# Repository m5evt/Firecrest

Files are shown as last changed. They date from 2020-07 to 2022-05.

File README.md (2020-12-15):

# Firecrest
This project is a dual band band HF CW transceiver design with a focus on portable operating. The design is realised across 3 stacked PCBs and the receiver is very similar to the N7VE/Norcal NC2030 and the transmitter PA is very similar to the KD1JV series of MTR rigs. This is not a kit, I intend to write a set of instruction to allow someone else with the appropriate skills to source their own components and build this radio.

Further information is on the [wiki](https://github.com/m5evt/Firecrest/wiki/).

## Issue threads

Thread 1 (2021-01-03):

Kicad files unproven

m5evt, 2021-01-03:
The hardware schematic and PCB files were imported from Eagle PCB. The gerbers from this (eagle) project have been ordered and the boards have been built. These are here [https://github.com/m5evt/Firecrest/tree/master/hardware/gerbers](url). If someone wants to make a modification to the hardware and create new gerbers, please approach with care.

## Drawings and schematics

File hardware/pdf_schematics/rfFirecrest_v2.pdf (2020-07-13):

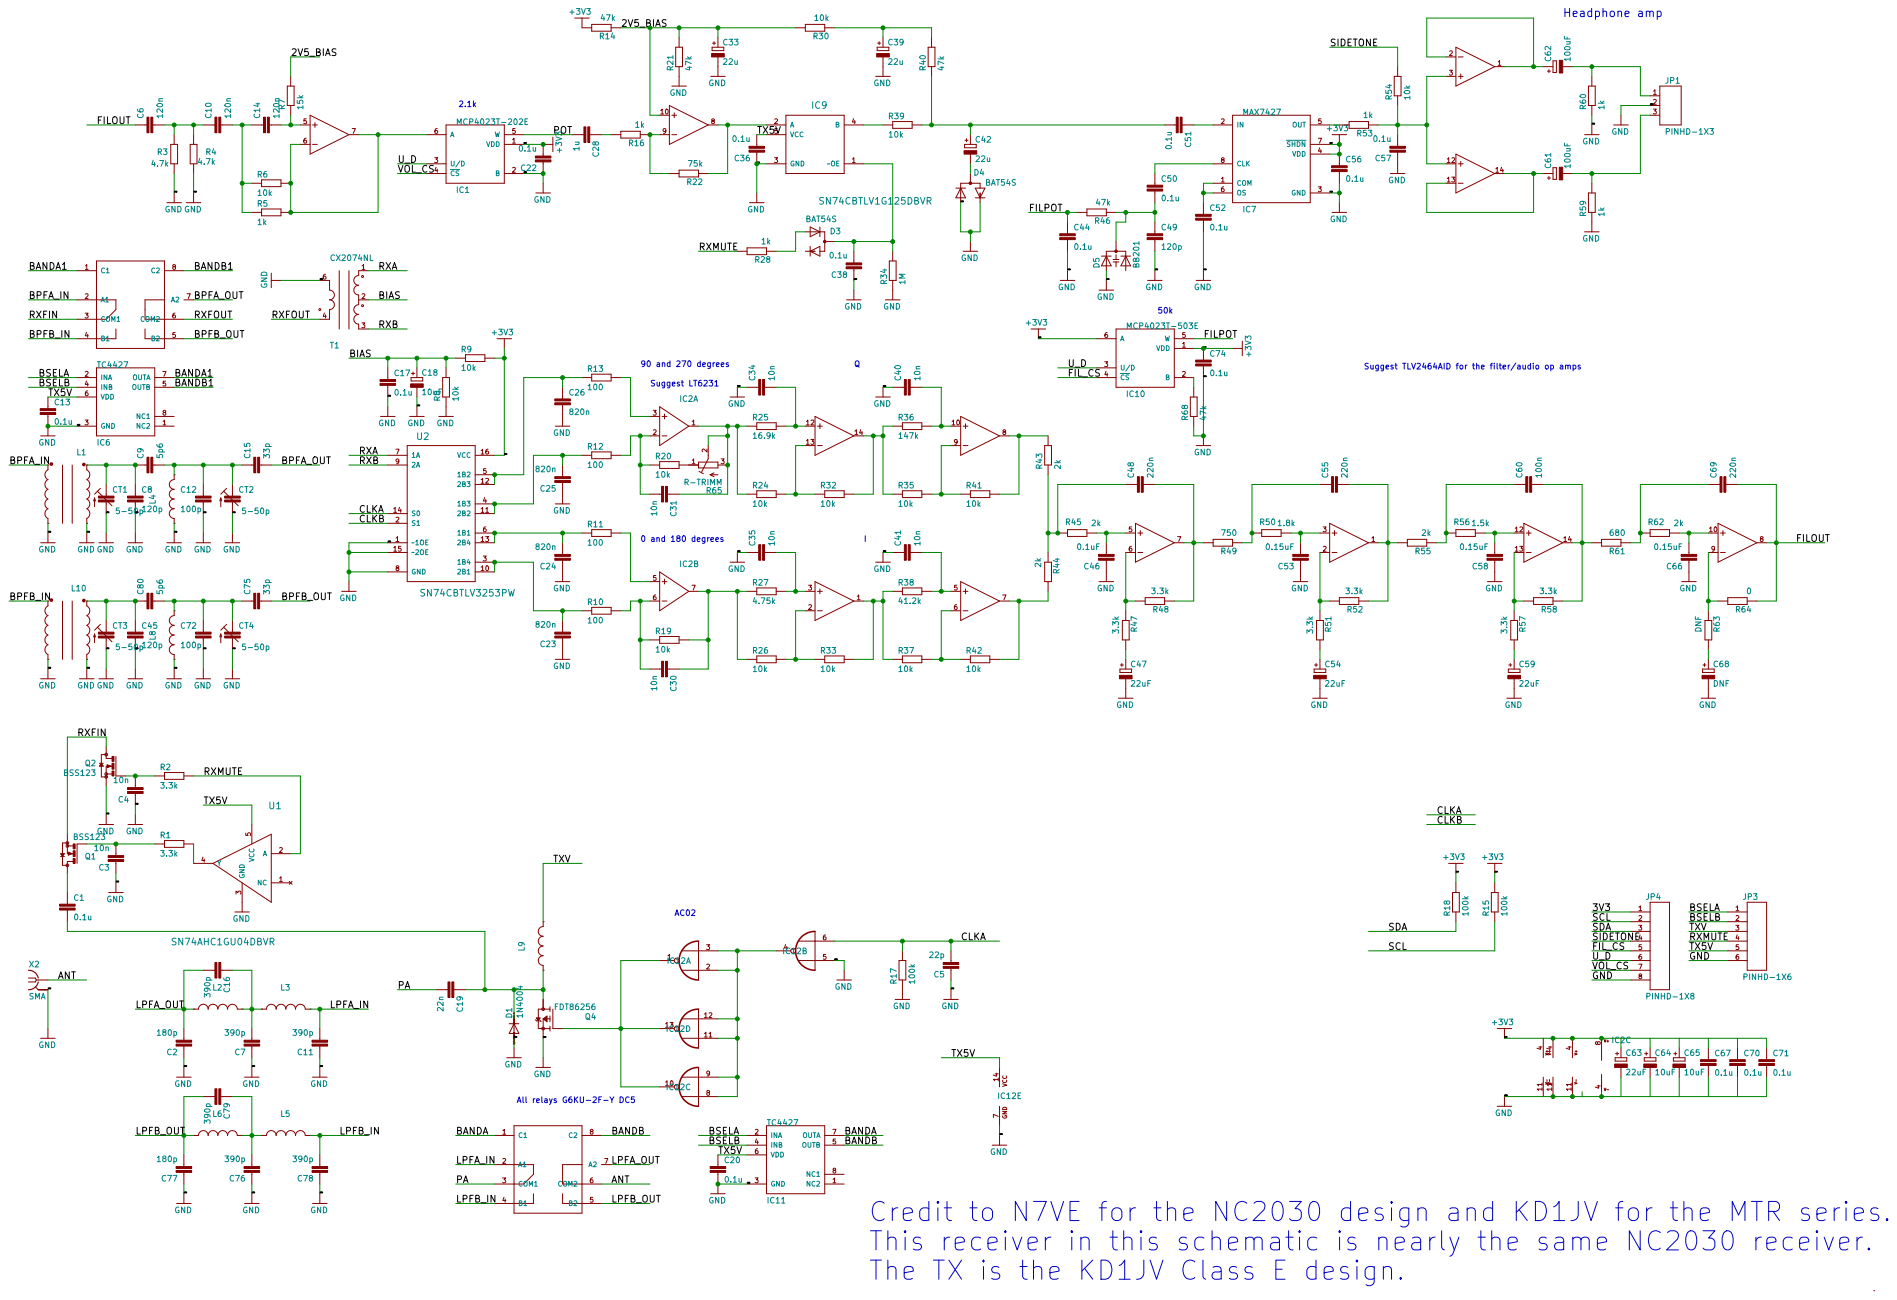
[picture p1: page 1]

Suggest TLV2464AID for the filter/audio op amps

Credit to N7VE for the NC2030 design and KD1JV for the MTR series.
This receiver in this schematic is nearly the same NC2030 receiver.
The TX is the KD1JV Class E design.

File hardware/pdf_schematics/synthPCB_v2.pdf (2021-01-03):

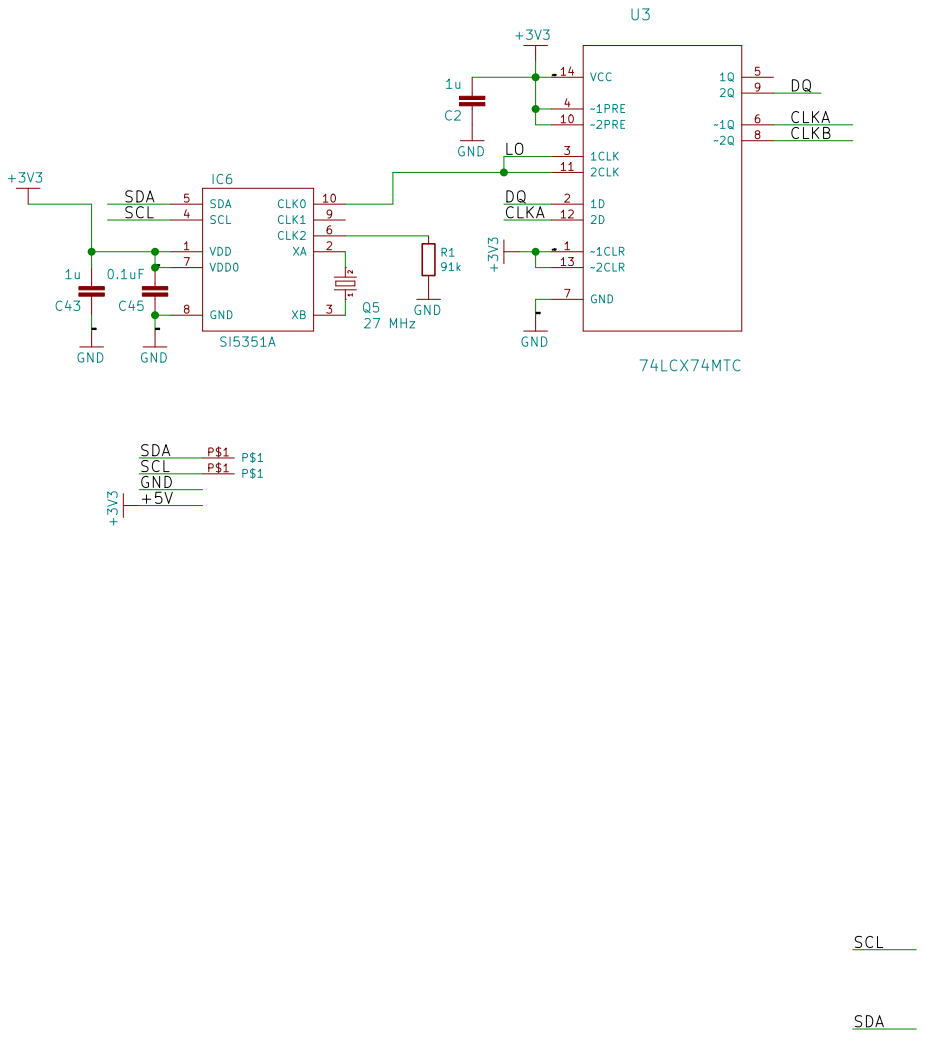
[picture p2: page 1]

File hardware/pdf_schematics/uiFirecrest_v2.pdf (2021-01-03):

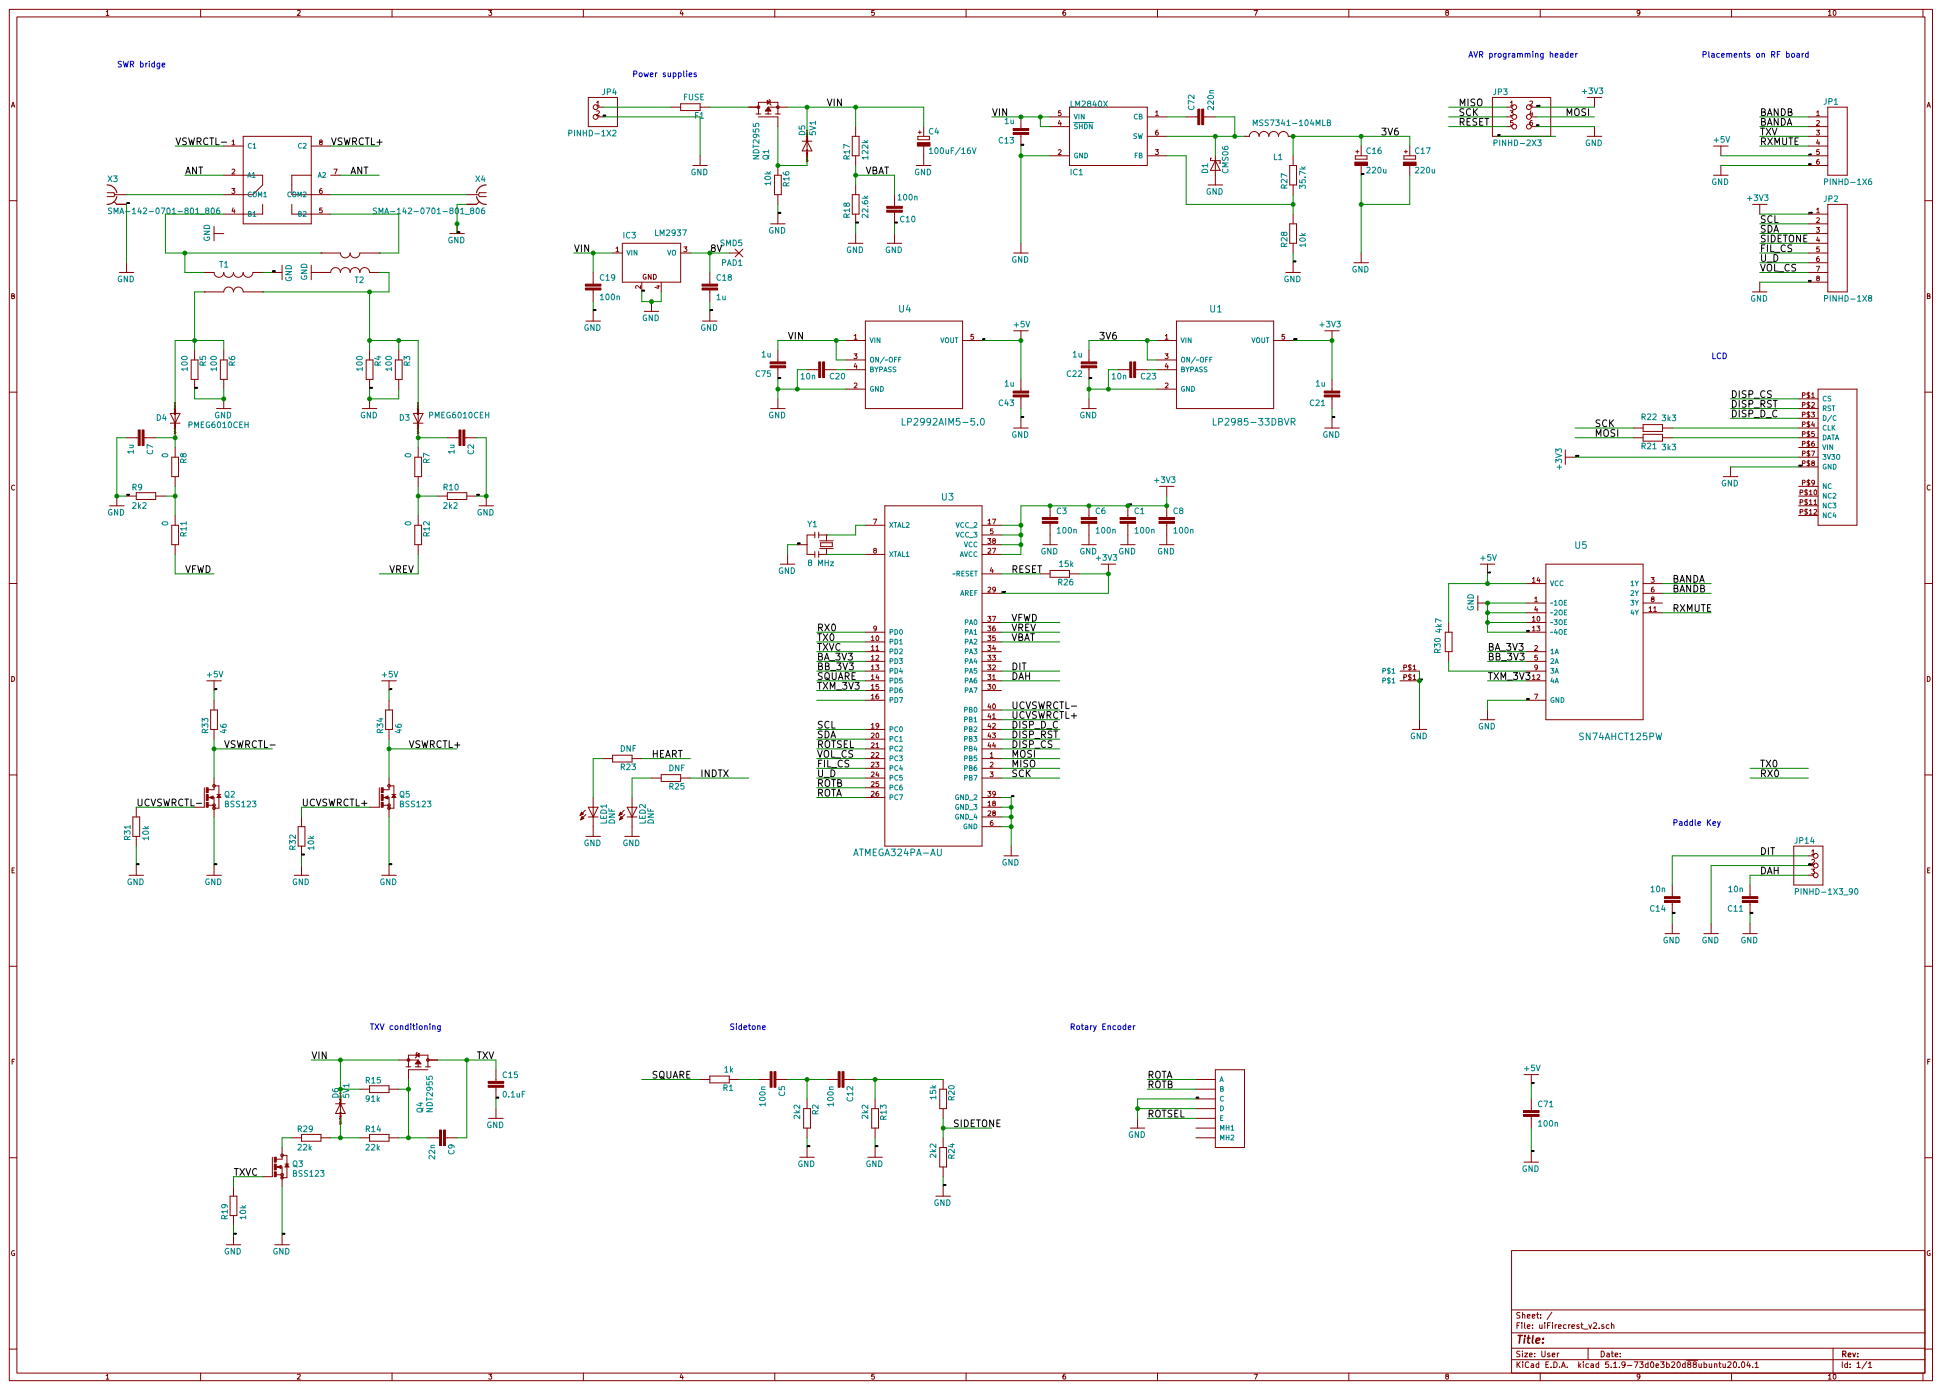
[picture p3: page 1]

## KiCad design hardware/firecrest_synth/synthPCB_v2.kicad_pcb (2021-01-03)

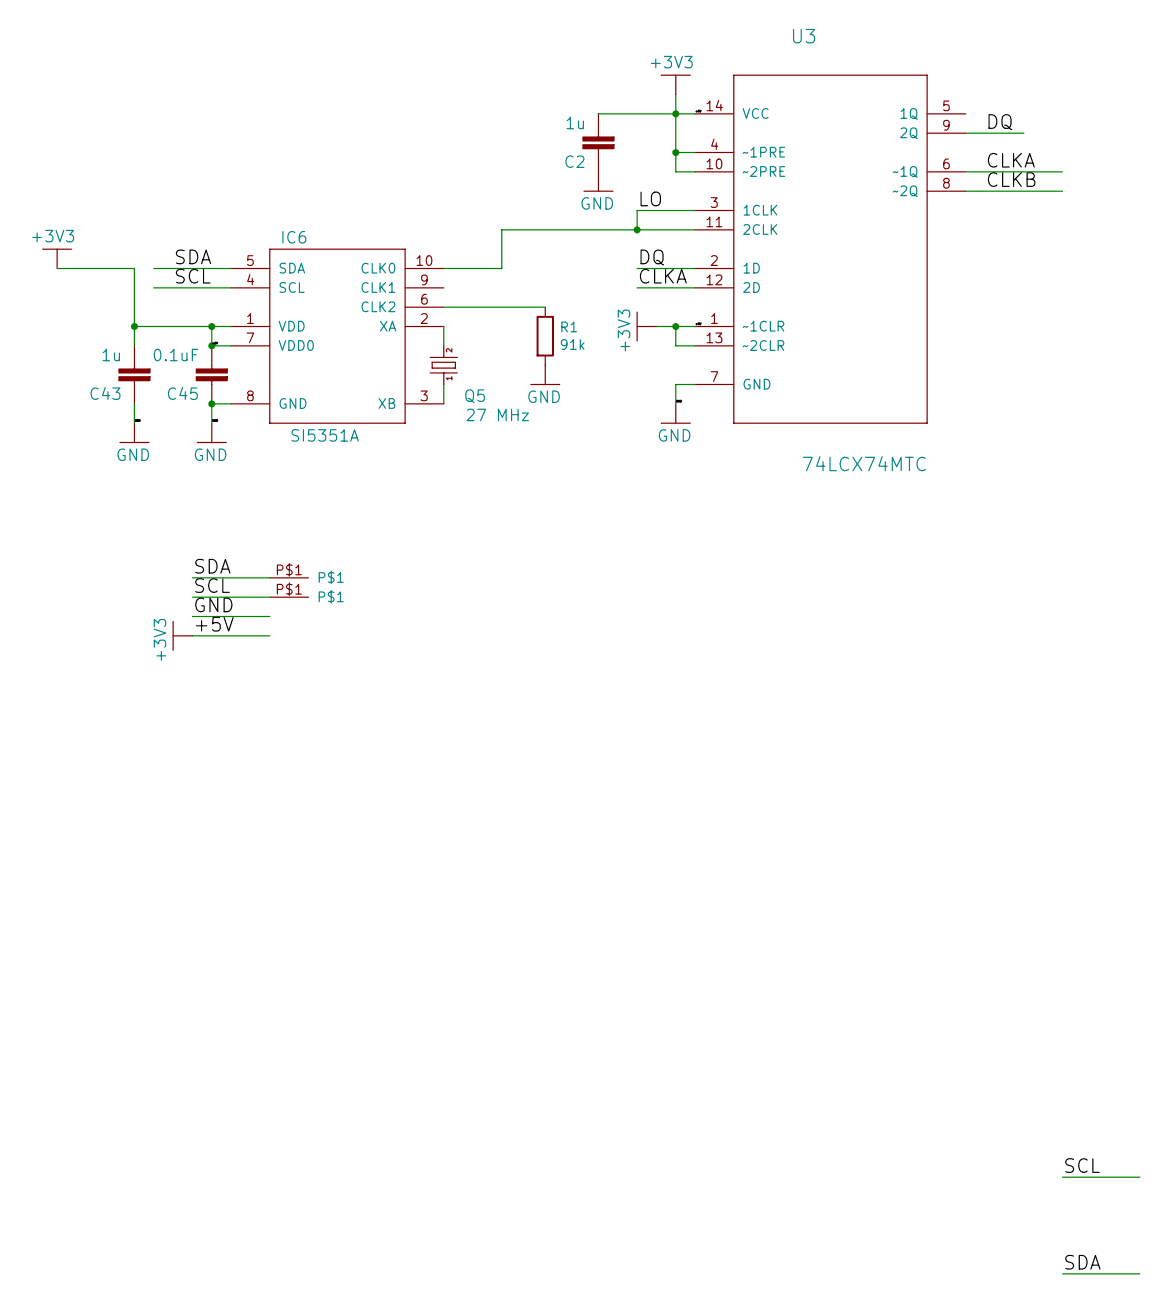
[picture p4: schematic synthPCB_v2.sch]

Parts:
C2, C43: 1u; C0603K
C45: 0.1uF; C0603K
IC6: SI5351A; MSOP10
Q5: 27 MHz; CTS406
R1: 91k; R_0603_1608Metric_Pad0.98x0.95mm_HandSolder
U3: 74LCX74MTC; SOP65P640X120-14N
U$5, U$6: EDGEPAD

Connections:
+5V: C2.2, C43.2, C45.2, IC6.1 (VDD), IC6.7 (VDD0), U3.1 (~~1CLR), U3.4 (~~1PRE), U3.10 (~~2PRE), U3.13 (~~2CLR), U3.14 (VCC)
/CLKA: U3.6 (~~1Q), U3.12 (2D)
/CLKB: U3.8 (~~2Q)
/DQ: U3.2 (1D), U3.9 (2Q)
/LO: IC6.10 (CLK0), U3.3 (1CLK), U3.11 (2CLK)
/SCL: IC6.4 (SCL), U$6.P$1
/SDA: IC6.5 (SDA), U$5.P$1
GND: C2.1, C43.1, C45.1, IC6.8 (GND), R1.2, U3.7 (GND)
unnamed: IC6.2 (XA), Q5.3 (2)
unnamed: IC6.3 (XB), Q5.1
unnamed: IC6.6 (CLK2), R1.1

Board: 2 copper layers, 13 parts (0 on the bottom side), 10 nets.

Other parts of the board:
@HOLE0, @HOLE1, @HOLE2, @HOLE3: (no value)

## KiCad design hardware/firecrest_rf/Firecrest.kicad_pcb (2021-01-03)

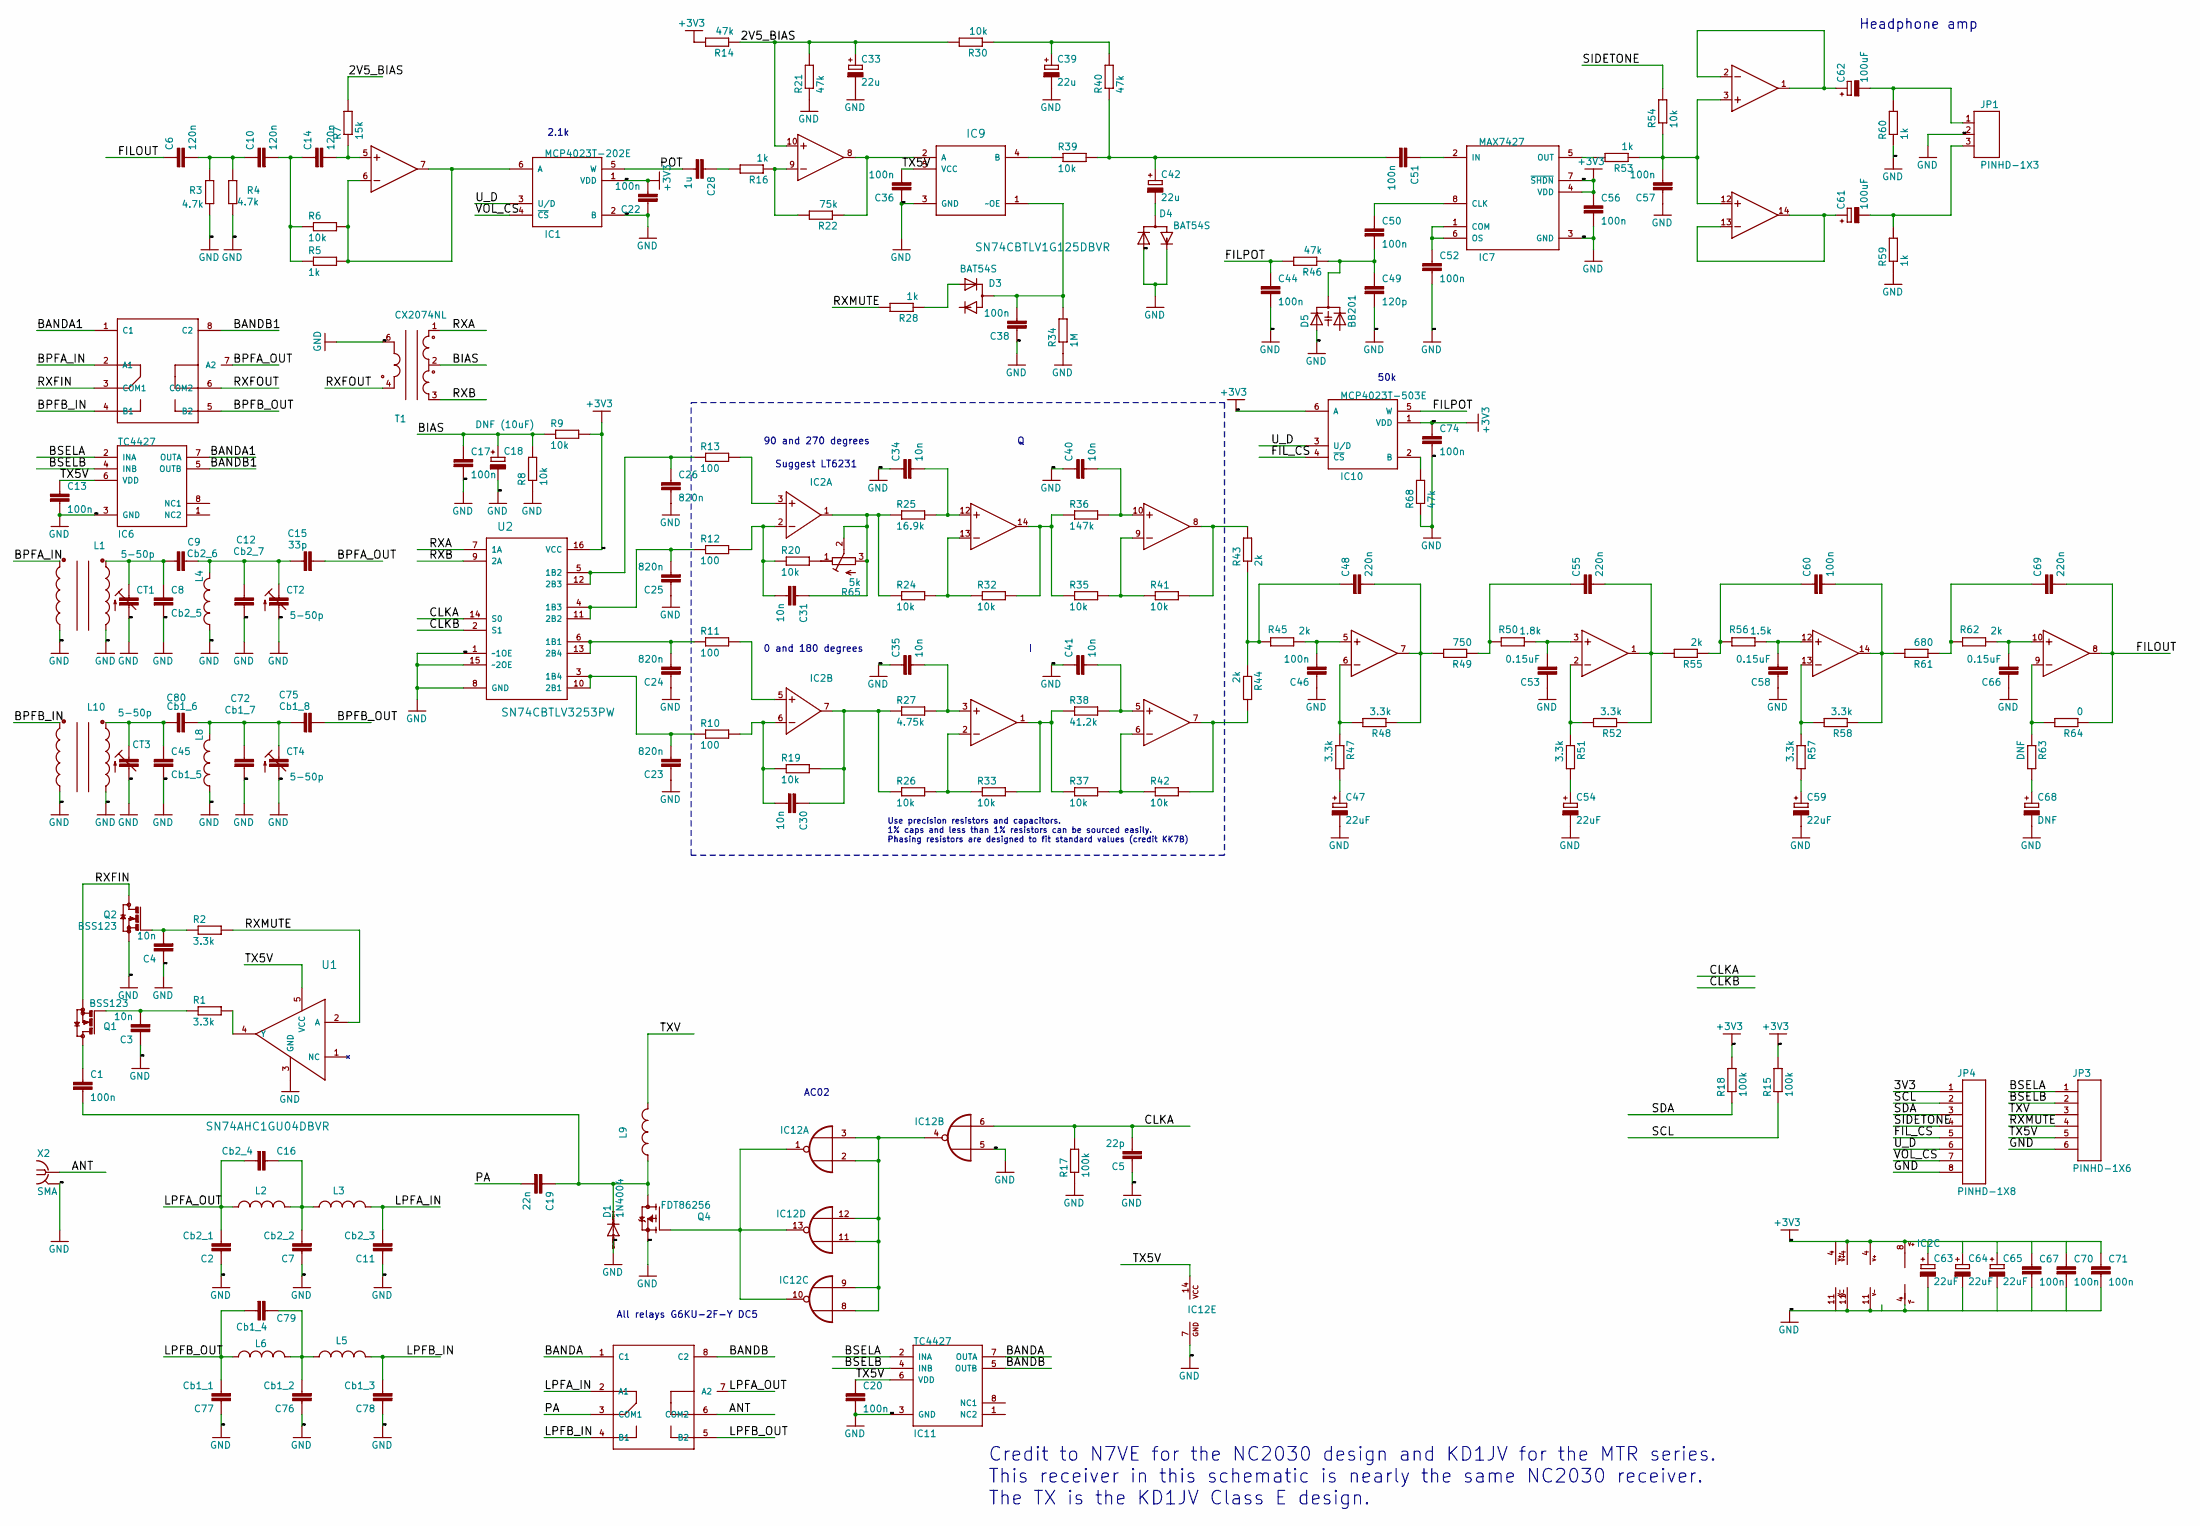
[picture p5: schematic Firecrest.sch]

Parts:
C1: 100n; C0805K
C2: Cb2_1; C0805K
C3, C4, C30, C31, C34, C35, C40, C41: 10n; C0603K
C5: 22p; C0603K
C6, C10, C14: 120n; C0603K
C7: Cb2_2; C0805K
C8: Cb2_5; C0603K
C9: Cb2_6; C0603K
C11: Cb2_3; C0805K
C12: Cb2_7; C0603K
C13, C17, C20, C22, C36, C38, C44, C46, C50, C51, C52, C56, C57, C60, C67, C70, C71, C74: 100n; C0603K
C15: 33p; C0603K
C16: Cb2_4; C0805K
C18: DNF (10uF); SMC_B
C19: 22n; C0805K
C23, C24, C25, C26: 820n; C0603K
C28: 1u; C0603K
C33, C39, C42: 22u; SMC_B
C45: Cb1_5; C0603K
C47, C54, C59, C63, C64, C65: 22uF; SMC_B
C48, C55, C69: 220n; C0603K
C49: 120p; C0603K
C53, C58, C66: 0.15uF; C0603K
C61, C62: 100uF; SMC_B
C68: DNF; SMC_B
C72: Cb1_7; C0603K
C75: Cb1_8; C0603K
C76: Cb1_2; C0805K
C77: Cb1_1; C0805K
C78: Cb1_3; C0805K
C79: Cb1_4; C0805K
C80: Cb1_6; C0603K
CT1, CT2, CT3, CT4: 5-50p; MURATA_TRIM
D1: 1N4004; DO41-10
D3, D4: BAT54S; SOT23
D5: BB201; SOT23
IC1: MCP4023T-202E; SOT23-6
IC2: LT6231; S8
IC4, IC5, IC8: TLV2464AID; SO14
IC6, IC11: TC4427; MSOP8
IC7: MAX7427; MSOP8
IC9: SN74CBTLV1G125DBVR; SOT95P280X145-5N
IC10: MCP4023T-503E; SOT23-6
IC12: 7402D; SO14
JP1: PINHD-1X3; 1X03
JP3: PINHD-1X6; 1X06
JP4: PINHD-1X8; 1X08
K1, K2: G6KU_OMRON
L1, L10: T30; T37_TRANSFORMER
L2, L3, L4, L6, L8: T30; T37_INDUCTOR
L5: T37; T37_INDUCTOR
L9: T37-43; T37_INDUCTOR
Q1, Q2: BSS123; SOT23
Q4: FDT86256; SOT223
R1, R2, R47, R48, R51, R52, R57, R58: 3.3k; R0603
R3, R4: 4.7k; R0603
R5, R16, R28, R53, R59, R60: 1k; R0603
R6, R8, R9, R19, R20, R24, R26, R30, R32, R33, R35, R37, R39, R41, R42, R54: 10k; R0603
R7: 15k; R0603
R10, R11, R12, R13: 100; R0603
R14, R21, R40, R46, R68: 47k; R0603
R15, R17, R18: 100k; R0603
R22: 75k; R0603
R25: 16.9k; R0603
R27: 4.75k; R0603
R34: 1M; R0603
R36: 147k; R0603
R38: 41.2k; R0603
R43, R44, R45, R55, R62: 2k; R0603
R49: 750; R0603
R50: 1.8k; R0603
R56: 1.5k; R0603
R61: 680; R0603
R63: DNF; R0603
R64: 0; R0603
R65: 5k; BOURNS3306W
T1: CX2074NL
U1: SN74AHC1GU04DBVR; SOT95P280X145-5N
U2: SN74CBTLV3253PW; SOP65P640X120-16N
X2: SMA; J502-ND-142-0701-801_806

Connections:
+5V: C22.2, C56.1, C63.+, C64.+, C65.+, C67.1, C70.1, C71.1, C74.1, IC1.1 (VDD), IC2.8 (V+), IC4.4 (V+), IC5.4 (V+), IC7.4 (VDD), IC7.7 (~SHDN), IC8.4 (V+), IC10.1 (VDD), IC10.6 (A), JP4.1, R9.2, R14.2, R15.2, R18.2, U2.16 (VCC)
/2V5_BIAS: C33.+, IC8.10 (+IN), R7.2, R14.1, R21.2, R30.2
/ANT: K2.6 (COM2), X2.1
/BANDA: IC11.7 (OUTA), K2.1 (C1)
/BANDA1: IC6.7 (OUTA), K1.1 (C1)
/BANDB: IC11.5 (OUTB), K2.8 (C2)
/BANDB1: IC6.5 (OUTB), K1.8 (C2)
/BIAS: C17.1, C18.+, R8.2, R9.1, T1.2
/BPFA_IN: K1.2 (A1), L1.C2B
/BPFA_OUT: C15.2, K1.7 (A2)
/BPFB_IN: K1.4 (B1), L10.C2B
/BPFB_OUT: C75.2, K1.5 (B2)
/BSELA: IC6.2 (INA), IC11.2 (INA), JP3.1
/BSELB: IC6.4 (INB), IC11.4 (INB), JP3.2
/CLKA: C5.2, IC12.6 (I1), R17.2, U2.14 (S0)
/CLKB: U2.2 (S1)
/FILOUT: C6.1, C69.2, IC5.8 (OUT), R64.1
/FILPOT: C44.1, IC10.5 (W), R46.2
/FIL_CS: IC10.4 (~CS), JP4.5
/LPFA_IN: C11.2, K2.2 (A1), L3.CA
/LPFA_OUT: C2.2, C16.2, K2.7 (A2), L2.CB
/LPFB_IN: C78.2, K2.4 (B1), L5.CA
/LPFB_OUT: C77.2, C79.2, K2.5 (B2), L6.CB
/PA: C19.2, K2.3 (COM1)
/POT: C28.2, IC1.5 (W)
/RXA: T1.1, U2.7 (1A)
/RXB: T1.3, U2.9 (2A)
/RXFIN: K1.3 (COM1), Q1.2 (S), Q2.3 (D)
/RXFOUT: K1.6 (COM2), T1.4
/RXMUTE: JP3.4, R2.2, R28.2, U1.2 (A)
/SCL: JP4.2, R15.1
/SDA: JP4.3, R18.1
/SIDETONE: JP4.4, R54.2
/TX5V: C13.1, C20.1, C36.2, IC6.6 (VDD), IC9.5 (VCC), IC11.6 (VDD), IC12.14 (VCC), JP3.5, U1.5 (VCC)
/TXV: JP3.3, L9.CA
/U_D: IC1.3 (U/D), IC10.3 (U/D), JP4.6
/VOL_CS: IC1.4 (~CS), JP4.7
GND: C2.1, C3.1, C4.1, C5.1, C7.1, C8.2, C11.1, C12.2, C13.2, C17.2, C18.-, C20.2, C22.1, C23.1, C24.1, C25.1, C26.2, C33.-, C34.1, C35.1, C36.1, C38.1, C39.-, C40.1, C41.1, C44.2, C45.2, C46.1, C47.-, C49.2, C52.2, C53.1, C54.-, C56.2, C57.1, C58.1, C59.-, C63.-, C64.-, C65.-, C66.1, C67.2, C68.-, C70.2, C71.2, C72.2, C74.2, C76.1, C77.1, C78.1, CT1.P$1 (A), CT2.P$1 (A), CT3.P$1 (A), CT4.P$1 (A), D1.A, D4.1 (A1), D4.2 (C2), D5.1 (A1), IC1.2 (B), IC2.4 (V-), IC4.11 (V-), IC5.11 (V-), IC6.3 (GND), IC7.3 (GND), IC8.11 (V-), IC9.3 (GND), IC11.3 (GND), IC12.5 (I0), IC12.7 (GND), JP1.2, JP3.6, JP4.8, L1.C1A, L1.C2A, L4.CB, L8.CB, L10.C1A, L10.C2A, Q2.2 (S), Q4.3 (S), R3.1, R4.1, R8.1, R17.1, R21.1, R34.1, R59.1, R60.1, R68.1, T1.6, U1.3 (GND), U2.1 (~~1OE), U2.8 (GND), U2.15 (~~2OE), X2.G@1 (2), X2.G@2 (2), X2.G@3 (2), X2.G@4 (2)
unnamed: C1.1, Q1.3 (D)
unnamed: C1.2, C19.1, D1.C, L9.CB, Q4.2 (D), Q4.4 (D)
unnamed: C3.2, Q1.1 (G), R1.1
unnamed: C4.2, Q2.1 (G), R2.1
unnamed: C8.1, C9.1, CT1.P$2 (E), L1.C1B
unnamed: C6.2, C10.1, R3.2, R4.2
unnamed: C10.2, C14.1, R5.1, R6.1
unnamed: C9.2, C12.1, C15.1, CT2.P$2 (E), L4.CA
unnamed: C14.2, IC8.5 (+IN), R7.1
unnamed: C7.2, C16.1, L2.CA, L3.CB
unnamed: C23.2, R10.1, U2.3 (1B4), U2.10 (2B1)
unnamed: C24.2, R11.1, U2.6 (1B1), U2.13 (2B4)
unnamed: C25.2, R12.1, U2.4 (1B3), U2.11 (2B2)
unnamed: C26.1, R13.1, U2.5 (1B2), U2.12 (2B3)
unnamed: C28.1, R16.2
unnamed: C30.1, IC2.7 (OUT), R19.2, R26.1, R27.1
unnamed: C30.2, IC2.6 (-IN), R10.2, R19.1
unnamed: C31.1, IC2.1 (OUT), R24.1, R25.1, R65.2 (S), R65.3 (E)
unnamed: C31.2, IC2.2 (-IN), R12.2, R20.1
unnamed: C34.2, IC4.12 (+IN), R25.2
unnamed: C35.2, IC4.3 (+IN), R27.2
unnamed: C38.2, D3.3 (C1A2), IC9.1 (~~OE), R34.2
unnamed: C39.+, R30.1, R40.2
unnamed: C40.2, IC4.10 (+IN), R36.2
unnamed: C41.2, IC4.5 (+IN), R38.2
unnamed: C42.+, C51.2, R39.2, R40.1
unnamed: C42.-, D4.3 (C1A2)
unnamed: C45.1, C80.1, CT3.P$2 (E), L10.C1B
unnamed: C46.2, IC5.5 (+IN), R45.1
unnamed: C47.+, R47.2
unnamed: C48.1, R43.1, R44.1, R45.2
unnamed: C48.2, IC5.7 (OUT), R48.1, R49.2
unnamed: C49.1, C50.2, D5.3 (C), R46.1
unnamed: C50.1, IC7.8 (CLK)
unnamed: C51.1, IC7.2 (IN)
unnamed: C52.1, IC7.1 (COM), IC7.6 (OS)
unnamed: C53.2, IC5.3 (+IN), R50.1
unnamed: C54.+, R51.2
unnamed: C55.1, R49.1, R50.2
unnamed: C55.2, IC5.1 (OUT), R52.1, R55.2
unnamed: C57.2, IC8.3 (+IN), IC8.12 (+IN), R53.1, R54.1
unnamed: C58.2, IC5.12 (+IN), R56.1
unnamed: C59.+, R57.2
unnamed: C60.1, R55.1, R56.2
unnamed: C60.2, IC5.14 (OUT), R58.1, R61.2
unnamed: C61.+, IC8.13 (-IN), IC8.14 (OUT)
unnamed: C61.-, JP1.3, R59.2
unnamed: C62.+, IC8.1 (OUT), IC8.2 (-IN)
unnamed: C62.-, JP1.1, R60.2
unnamed: C66.2, IC5.10 (+IN), R62.1
unnamed: C68.+, R63.2
unnamed: C69.1, R61.1, R62.2
unnamed: C72.1, C75.1, C80.2, CT4.P$2 (E), L8.CA
unnamed: C76.2, C79.1, L5.CB, L6.CA
unnamed: D3.1 (A1), R28.1
unnamed: IC1.6 (A), IC8.6 (-IN), IC8.7 (OUT), R5.2, R6.2
unnamed: IC2.3 (+IN), R13.2
unnamed: IC2.5 (+IN), R11.2
unnamed: IC4.1 (OUT), R33.2, R37.1, R38.1
unnamed: IC4.2 (-IN), R26.2, R33.1
unnamed: IC4.6 (-IN), R37.2, R42.1
unnamed: IC4.7 (OUT), R42.2, R44.2
unnamed: IC4.8 (OUT), R41.2, R43.2
unnamed: IC4.9 (-IN), R35.2, R41.1
unnamed: IC4.13 (-IN), R24.2, R32.1
unnamed: IC4.14 (OUT), R32.2, R35.1, R36.1
unnamed: IC5.2 (-IN), R51.1, R52.2
unnamed: IC5.6 (-IN), R47.1, R48.2
unnamed: IC5.9 (-IN), R63.1, R64.2
unnamed: IC5.13 (-IN), R57.1, R58.2
unnamed: IC7.5 (OUT), R53.2
unnamed: IC8.8 (OUT), IC9.2 (A), R22.1
unnamed: IC8.9 (-IN), R16.1, R22.2
unnamed: IC9.4 (B), R39.1
unnamed: IC10.2 (B), R68.2
unnamed: IC12.1 (O), IC12.10 (O), IC12.13 (O), Q4.1 (G)
unnamed: IC12.2 (I0), IC12.3 (I1), IC12.4 (O), IC12.8 (I0), IC12.9 (I1), IC12.11 (I0), IC12.12 (I1)
unnamed: R1.2, U1.4 (Y)
unnamed: R20.2, R65.1 (A)

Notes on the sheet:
Headphone amp
90 and 270 degrees
0 and 180 degrees
2.1k
50k
AC02
Suggest LT6231
All relays G6KU-2F-Y DC5
Credit to N7VE for the NC2030 design and KD1JV for the MTR series. This receiver in this schematic is nearly the same NC2030 receiver. The TX is the KD1JV Class E design.
Use precision resistors and capacitors. 1% caps and less than 1% resistors can be sourced easily. Phasing resistors are designed to fit standard values (credit KK7B)

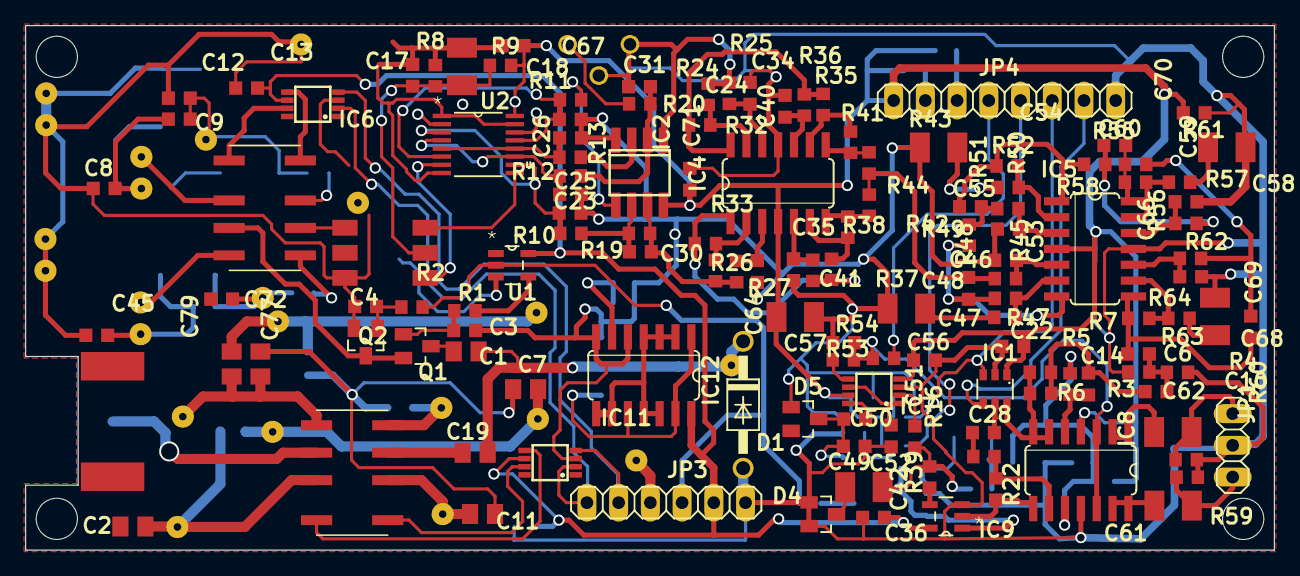
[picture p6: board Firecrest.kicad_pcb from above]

Board: 2 copper layers, 100.0 x 42.0 mm, 180 parts (0 on the bottom side), 116 nets.

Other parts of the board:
@HOLE0, @HOLE1, @HOLE2, @HOLE3: (no value)

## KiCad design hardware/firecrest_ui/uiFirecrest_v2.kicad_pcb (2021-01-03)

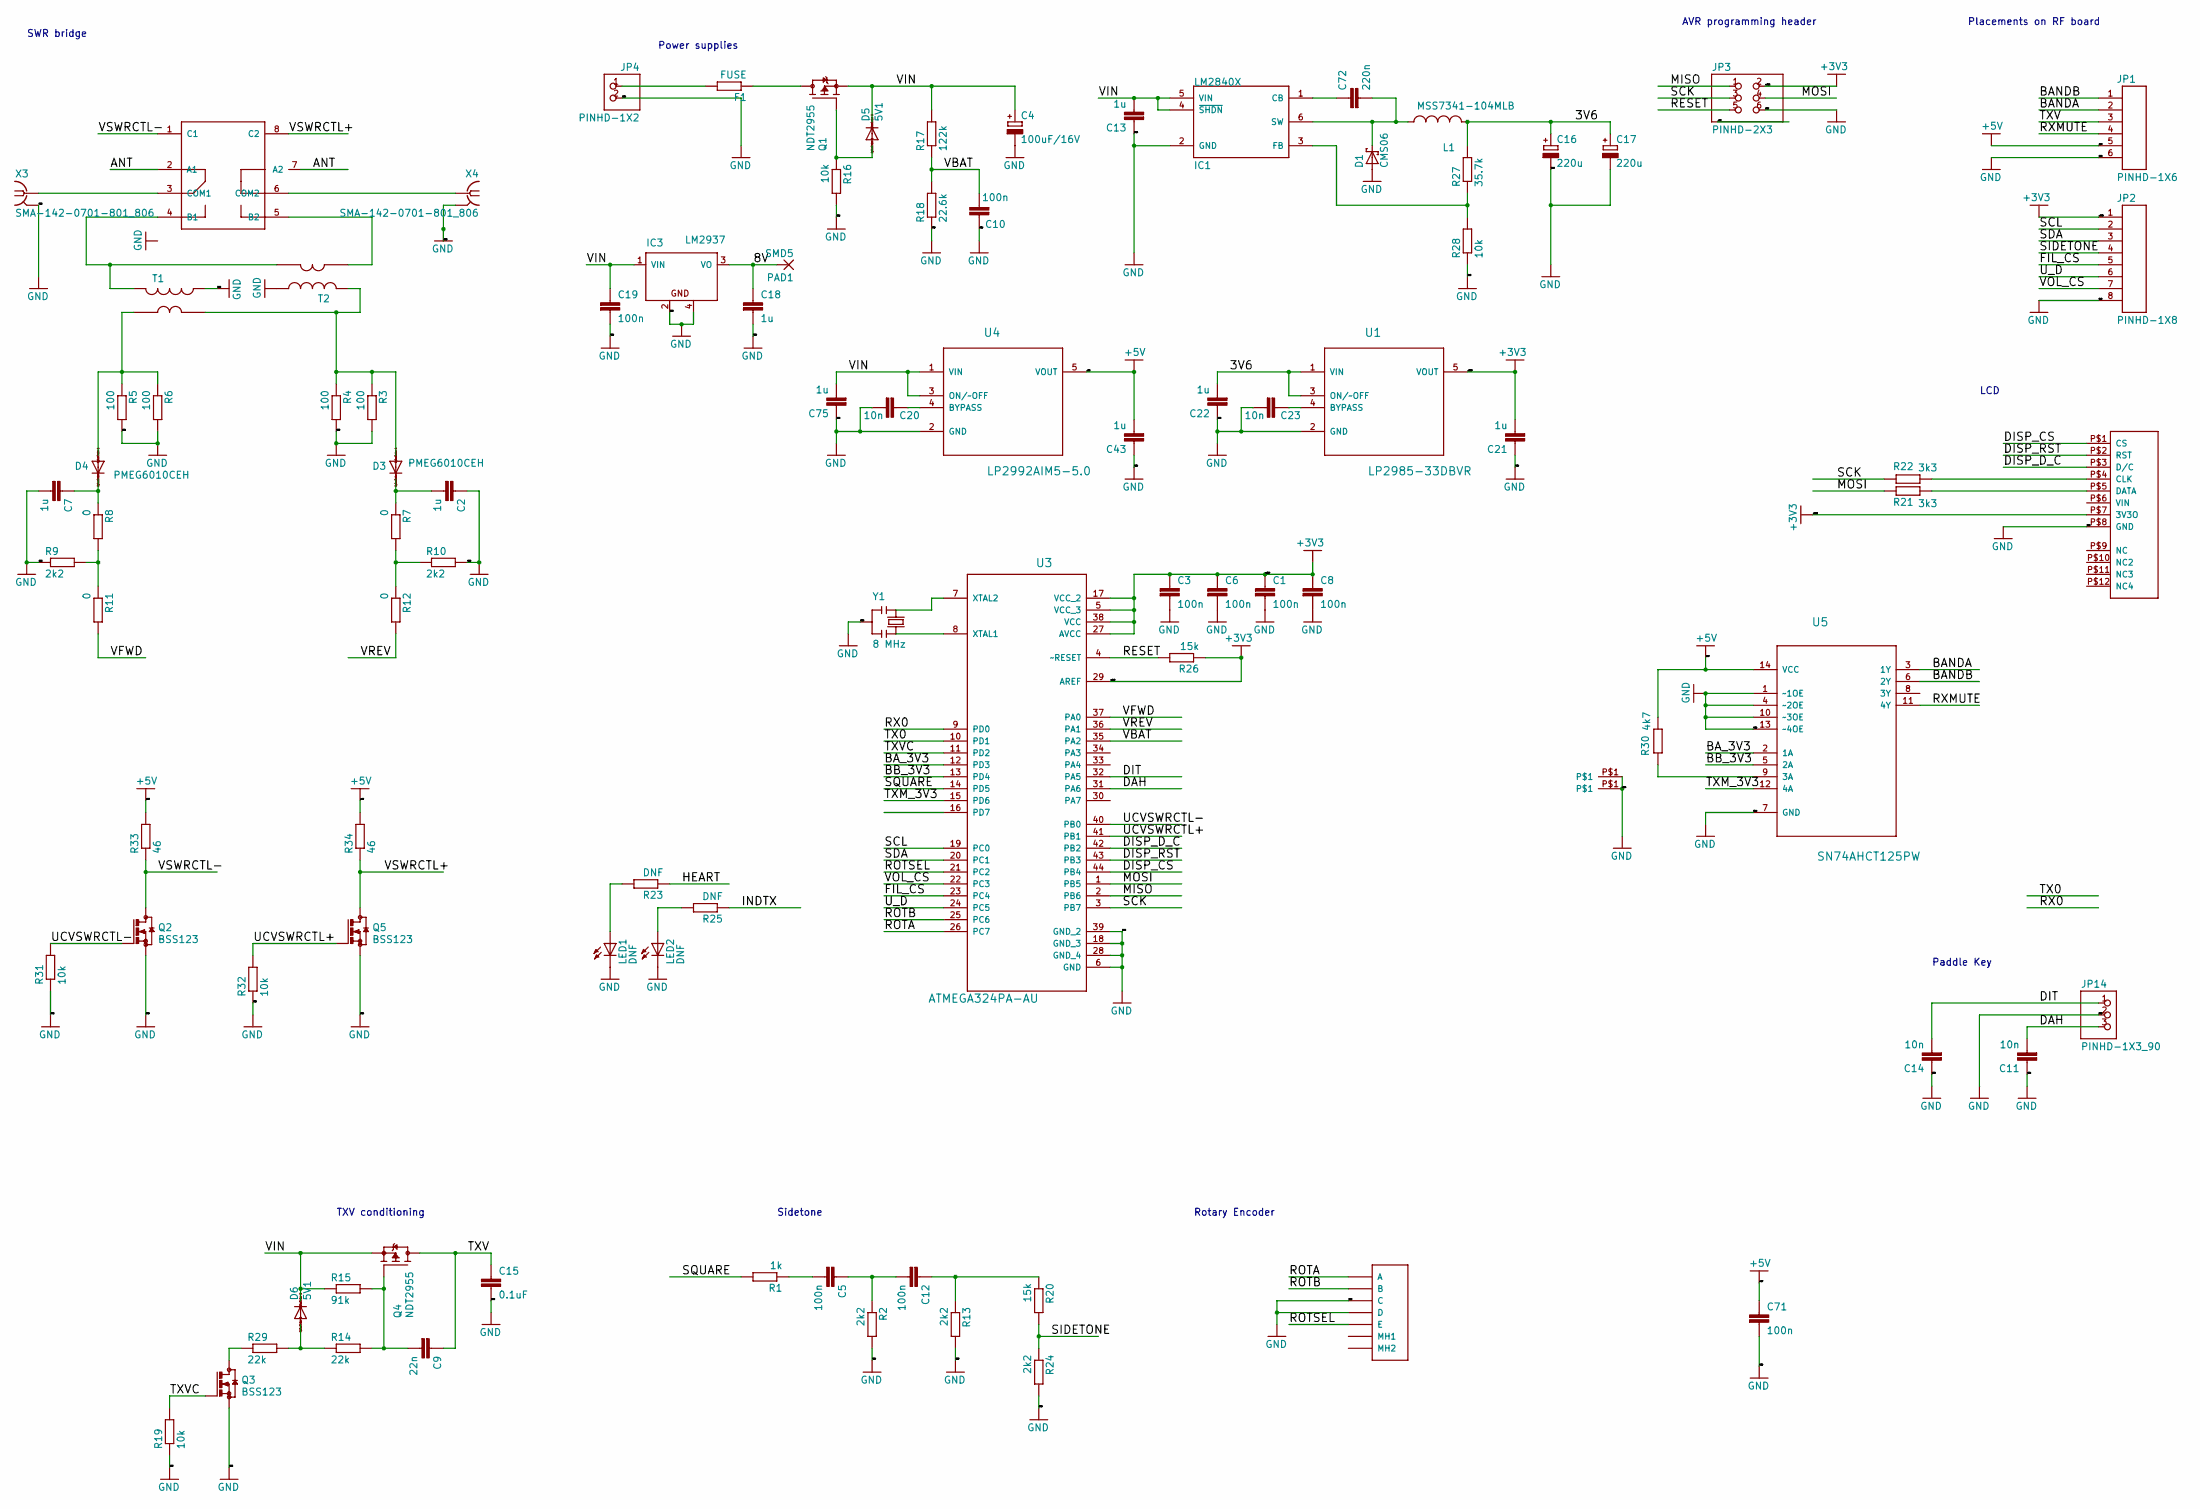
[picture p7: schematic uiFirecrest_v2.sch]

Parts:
C1, C3, C5, C6, C8, C10, C12, C71: 100n; C0603K
C2, C7, C13, C18, C43: 1u; C0805K
C4: 100uF/16V; SMC_D
C9: 22n; C0805K
C11, C14, C20, C23: 10n; C0603K
C15: 0.1uF; C0805K
C16, C17: 220u; SMC_D
C19: 100n; C0805K
C21, C22, C75: 1u; C0603K
C72: 220n; C0603K
D1: CMS06; CMS06_DIODE
D3, D4: PMEG6010CEH; SOD123
D5, D6: 5V1; SOD123
F1: FUSE; R1206W
IC1: LM2840X; SOT23-6
IC3: LM2937; SOT223
JP1: PINHD-1X6; 1X06
JP2: PINHD-1X8; 1X08
JP3: PINHD-2X3; 2X03
JP4: PINHD-1X2; 1X02
JP14: PINHD-1X3_90; 1X03_90
K1: G6KU_OMRON
L1: MSS7341-104MLB; LPS8045B-224MRB
LED1, LED2: DNF; SML0805
PAD1: SMD5; SMD2,54-5,08
Q1, Q4: NDT2955; SOT223
Q2, Q3, Q5: BSS123; SOT23
R1: 1k; R0603
R2, R9, R10, R13, R24: 2k2; R0603
R3, R4, R5, R6: 100; R0805
R7, R8: 0; R0603
R11, R12: 0; R0805
R14, R29: 22k; R0603
R15: 91k; R0603
R16, R19, R28, R31, R32: 10k; R0603
R17: 122k; R0603
R18: 22.6k; R0603
R20, R26: 15k; R0603
R21, R22: 3k3; R0603
R23, R25: DNF; R0603
R27: 35.7k; R0603
R30: 4k7; R0603
R33, R34: 46; R0603
T1, T2: T37-43; T37_THRU
U1: LP2985-33DBVR; SOT95P280X145-5N
U3: ATMEGA324PA-AU; QFP80P1200X1200X120-44N
U4: LP2992AIM5-5.0; SOT95P280X145-5N
U5: SN74AHCT125PW; SOP65P640X120-14N
U$1: OLED; OLED_LCD
U$2: ROTENC
U$3, U$4: RFCAN; CAN
X3, X4: SMA-142-0701-801_806; J502-ND-142-0701-801_806
Y1: 8 MHz; RESONATOR

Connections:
+3V3: C1.1, C3.1, C6.1, C8.1, C21.2, JP2.1, JP3.2, R26.1, U1.5 (VOUT), U3.5 (VCC_3), U3.17 (VCC_2), U3.27 (AVCC), U3.29 (AREF), U3.38 (VCC), U$1.P$7 (3V3O)
+5V: C43.2, C71.1, JP1.5, R30.1, R33.2, R34.2, U4.5 (VOUT), U5.14 (VCC)
/3V6: C16.+, C17.+, C22.2, L1.1 (CA), R27.2, U1.1 (VIN), U1.3 (ON/~~OFF)
/8V: C18.1, IC3.3 (VO), PAD1.1
/ANT: K1.2 (A1), K1.7 (A2)
/BANDA: JP1.2, U5.3 (1Y)
/BANDB: JP1.1, U5.6 (2Y)
/BA_3V3: U3.12 (PD3), U5.2 (1A)
/BB_3V3: U3.13 (PD4), U5.5 (2A)
/DAH: C11.2, JP14.3, U3.31 (PA6)
/DISP_CS: U3.44 (PB4), U$1.P$1 (CS)
/DISP_D_C: U3.42 (PB2), U$1.P$3 (D/C)
/DISP_RST: U3.43 (PB3), U$1.P$2 (RST)
/DIT: C14.2, JP14.1, U3.32 (PA5)
/FIL_CS: JP2.5, U3.23 (PC4)
/HEART: R23.1
/INDTX: R25.1
/MISO: JP3.1, U3.2 (PB6)
/MOSI: JP3.4, R21.2, U3.1 (PB5)
/RESET: JP3.5, R26.2, U3.4 (~~RESET)
/ROTA: U3.26 (PC7), U$2.P$1 (A)
/ROTB: U3.25 (PC6), U$2.P$2 (B)
/ROTSEL: U3.21 (PC2), U$2.P$5 (E)
/RX0: U3.9 (PD0)
/RXMUTE: JP1.4, U5.11 (4Y)
/SCK: JP3.3, R22.2, U3.3 (PB7)
/SCL: JP2.2, U3.19 (PC0)
/SDA: JP2.3, U3.20 (PC1)
/SIDETONE: JP2.4, R20.2, R24.1
/SQUARE: R1.2, U3.14 (PD5)
/TX0: U3.10 (PD1)
/TXM_3V3: U3.15 (PD6), U5.12 (4A)
/TXV: C9.1, C15.1, JP1.3, Q4.2 (D), Q4.4 (D)
/TXVC: Q3.1 (G), R19.2, U3.11 (PD2)
/UCVSWRCTL+: Q5.1 (G), R32.2, U3.41 (PB1)
/UCVSWRCTL-: Q2.1 (G), R31.2, U3.40 (PB0)
/U_D: JP2.6, U3.24 (PC5)
/VBAT: C10.2, R17.1, R18.2, U3.35 (PA2)
/VFWD: R11.2, U3.37 (PA0)
/VIN: C4.+, C13.2, C19.1, C75.2, D5.C, D6.C, IC1.4 (~SHDN), IC1.5 (VIN), IC3.1 (VIN), Q1.3 (S), Q4.3 (S), R15.1, R17.2, U4.1 (VIN), U4.3 (ON/~~OFF)
/VOL_CS: JP2.7, U3.22 (PC3)
/VREV: R12.2, U3.36 (PA1)
/VSWRCTL+: K1.8 (C2), Q5.3 (D), R34.1
/VSWRCTL-: K1.1 (C1), Q2.3 (D), R33.1
GND: C1.2, C2.1, C3.2, C4.-, C6.2, C7.2, C8.2, C10.1, C11.1, C13.1, C14.1, C15.2, C16.-, C17.-, C18.2, C19.2, C20.2, C21.1, C22.1, C23.2, C43.1, C71.2, C75.1, D1.AN (A), IC1.2 (GND), IC3.2 (GND@1), IC3.4 (GND@2), JP1.6, JP2.8, JP3.6, JP4.2, JP14.2, LED1.C, LED2.C, Q2.2 (S), Q3.2 (S), Q5.2 (S), R2.2, R3.2, R4.2, R5.2, R6.2, R9.1, R10.2, R13.2, R16.2, R18.1, R19.1, R24.2, R28.1, R31.1, R32.1, T1.C1B (BA), T2.C1B (BA), U1.2 (GND), U3.6 (GND), U3.18 (GND_3), U3.28 (GND_4), U3.39 (GND_2), U4.2 (GND), U5.1 (~~1OE), U5.4 (~~2OE), U5.7 (GND), U5.10 (~~3OE), U5.13 (~~4OE), U$1.P$8 (GND), U$2.P$3 (C), U$2.P$4 (D), U$3.P$1, U$4.P$1, X3.G@1 (2), X3.G@2 (2), X3.G@3 (2), X3.G@4 (2), X4.G@1 (2), X4.G@2 (2), X4.G@3 (2), X4.G@4 (2), Y1.2
unnamed: C2.2, D3.C, R7.1
unnamed: C5.2, R1.1
unnamed: C7.1, D4.C, R8.1
unnamed: C9.2, Q4.1 (G), R14.2, R15.2
unnamed: C12.1, R13.1, R20.1
unnamed: C5.1, C12.2, R2.1
unnamed: C20.1, U4.4 (BYPASS)
unnamed: C23.1, U1.4 (BYPASS)
unnamed: C72.1, IC1.1 (CB)
unnamed: C72.2, D1.CAT (C), IC1.6 (SW), L1.2 (CB)
unnamed: D3.A, R3.1, R4.1, T1.THRU1 (SA), T2.C2A (BB)
unnamed: D4.A, R5.1, R6.1, T1.THRU2 (SB)
unnamed: D5.A, Q1.1 (G), R16.1
unnamed: D6.A, R14.1, R29.2
unnamed: F1.1, Q1.2 (D), Q1.4 (D)
unnamed: F1.2, JP4.1
unnamed: IC1.3 (FB), R27.1, R28.2
unnamed: K1.3 (COM1), X3.1
unnamed: K1.4 (B1), T1.C2A (BB), T2.THRU1 (SA)
unnamed: K1.5 (B2), T2.THRU2 (SB)
unnamed: K1.6 (COM2), X4.1
unnamed: LED1.A, R23.2
unnamed: LED2.A, R25.2
unnamed: Q3.3 (D), R29.1
unnamed: R7.2, R10.1, R12.1
unnamed: R8.2, R9.2, R11.1
unnamed: R21.1, U$1.P$5 (DATA)
unnamed: R22.1, U$1.P$4 (CLK)
unnamed: R30.2, U5.9 (3A)
unnamed: U3.7 (XTAL2), Y1.1
unnamed: U3.8 (XTAL1), Y1.3

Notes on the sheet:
Placements on RF board
SWR bridge
LCD
Paddle Key
Power supplies
AVR programming header
TXV conditioning
Rotary Encoder
Sidetone

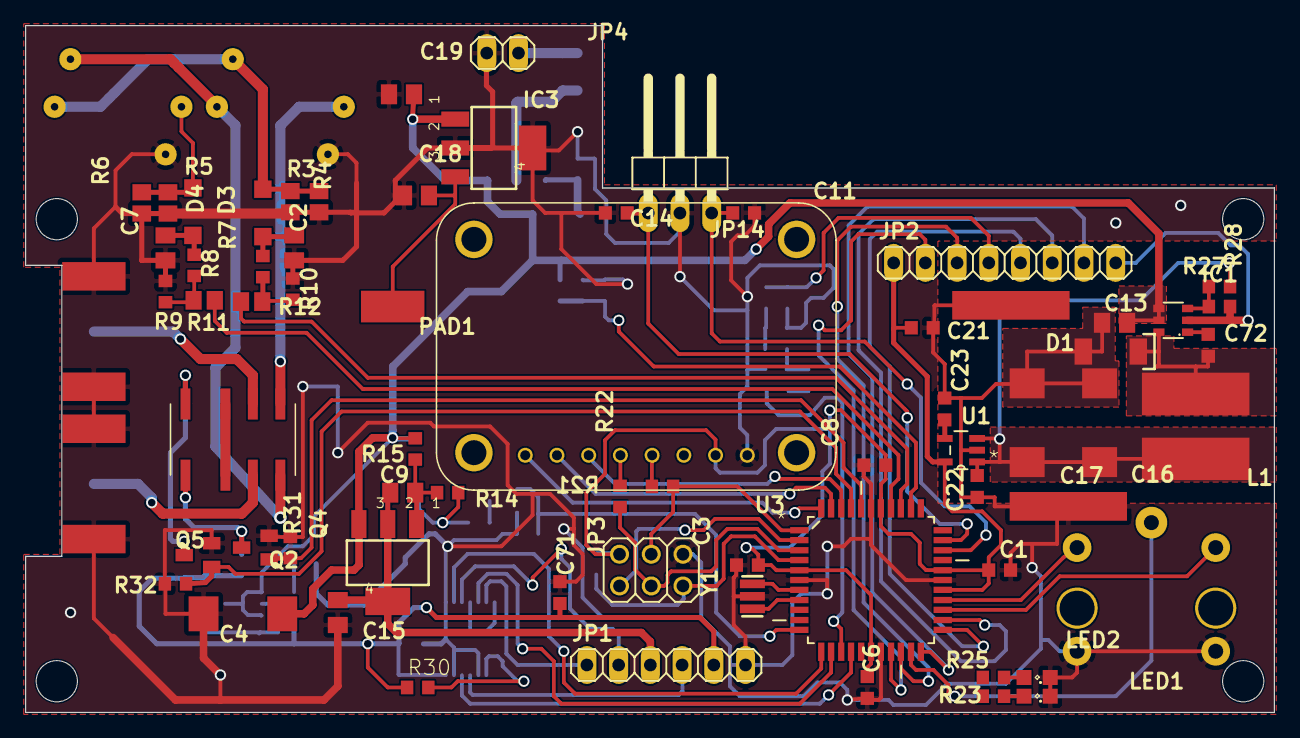
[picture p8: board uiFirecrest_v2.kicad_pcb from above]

Board: 2 copper layers, 100.0 x 55.0 mm, 101 parts (0 on the bottom side), 72 nets.

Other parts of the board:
@HOLE0, @HOLE1, @HOLE2, @HOLE3: (no value)

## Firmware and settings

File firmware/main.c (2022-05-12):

/* 
 * Copyright 2021 m5evt
 * 
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
 */

/********************************************************************************
Includes
********************************************************************************/
#include <avr/io.h>
#include <stdbool.h>
#include <avr/interrupt.h>
#include <stdlib.h>
#include <avr/pgmspace.h>
#include <inttypes.h>
#include <string.h> 
#include <stdio.h>
#include <math.h>
#include <avr/eeprom.h>

#include "helper.h"
#include "firecrest.h"
//VFO
#include "i2c.h"
#include "si5351a.h"


/*************************************************************************
//Defines
*************************************************************************/
// define CPU frequency in Mhz here if not defined in Makefile
#ifndef F_CPU
#define F_CPU 8000000UL
#endif

volatile unsigned int rotEncChange = 0;
volatile unsigned int storedRotA = 0;
volatile unsigned int storedRotB = 0;

volatile unsigned int storedRot = 0;
uint8_t battery_state;
uint8_t enableMemoryReplay;

uint8_t straight_key = 0;
uint16_t countDownMemoryTimer = 0;
uint8_t memoryReplayNow;
uint8_t sk_state = 0;
uint16_t sk_timer;

volatile uint8_t txKeyed;

uint8_t magic EEMEM = MAGPAT;	// Needs to contain 'A5' if mem is valid

// Settings for EEPROM
eesave_t ee_vars EEMEM;

char cqStr[] = "CQ CQ CQ de";

///============Function Prototypes=========/////////////////
static void initMicro(void);
static void serviceFreq(struct systemSettings *setting);
static void service_straight_key(void);
static uint8_t serviceMenu(struct menuStateMachine *state, struct systemSettings *setting);
static void serviceBattery(void);
static void filterUPone(void);
static void filterDOWNone(void);
static void volumeUPone(void);
static void volumeDOWNone(void);
static void memoryCQ(void);
static uint16_t serviceStep(uint8_t up, uint8_t down, uint16_t step);
static void ChangeBand(uint8_t band, struct systemSettings *setting);
static uint8_t serviceKeyerMode(uint8_t up, uint8_t down, uint8_t keyerMode);

/*************************************************************************
//Added from yack main.c
*************************************************************************/
#include "ssd1306.h"
#include "display.h"
#include "yack.h"

/*************************************************************************
//Main
*************************************************************************/
int main(void) {
	uint16_t i = 0;
	
	KEYTX = 0;
	rxMUTE = 1;
  // Default callsign
  strcpy(callStr, "M5EVT/P");    

  // EEPROM settings in RAM
  //struct 
  eesave_t ram_vars;
  
  // Read the EEPROM saved values  
	eeprom_read_block(&ram_vars, &ee_vars, sizeof(eesave_t));
    
  struct systemSettings mySettings;
	struct menuStateMachine myStateMachine;

	myStateMachine.currentState = 0;

	/**
	General AVR init
	**/
	initMicro();
  RFSWMINS = 0;
  RFSWPLUS = 0;
  yackbeat();
  RFSWMINS = 1;
	RFSWPLUS = 0;
  yackbeat();
  RFSWMINS = 0;
	RFSWPLUS = 0;  

  // Is the EEPROM valid?
	uint8_t magval = eeprom_read_byte(&magic); // Retrieve magic value
  if (magval == MAGPAT) {
    //Move this into a function
    strncpy(callStr, ram_vars.e_call, 12);

    mySettings.keyMode = ram_vars.e_kmod;    
    serviceKeyerMode(0,0,mySettings.keyMode);
        
    wpm = ram_vars.e_kwpm;
    mySettings.band = ram_vars.e_band;
    mySettings.filterMode = ram_vars.e_filt;
    mySettings.autoReplay = ram_vars.e_replay_time;
    mySettings.increment = ram_vars.e_increment;

  }
  else {
    // Corrupt EEPROM, load defaults
    mySettings.keyMode = 5;
    wpm = 18;
    // Wide filter
    mySettings.filterMode = 0;
    mySettings.autoReplay = 5;
    mySettings.band = 10;
    mySettings.increment = 1000;       
  }
  
  ChangeBand(mySettings.band, &mySettings);
    
	memoryReplayNow = 0;
	enableMemoryReplay = 0;
	
  myStateMachine.pbCounterOn = 0;	
  
	//OLED init and splash load
	ssd1306Init(SSD1306_EXTERNALVCC);
	ssd1306ClearScreen();
	ssd1306Refresh();
  sei(); 

	//VFO init
	i2c_init();
  si5351aSetInitFrequency(mySettings.freq);
  si5351aSetInitTXFrequency((mySettings.freq / 4) - TXOFFSET);
  si5351_clock_enable(SI5351_CLK2, 0);    

	//Keyer init
	yackinit();
    
	// Take pot to 0 value
	for (i=0;i<8;i++) {
		volumeDOWNone();
	}	
	
	for (i=0;i<4;i++) {
		volumeUPone();
		mySettings.volume = 4;	
	}
	
	// Take pot to NARROW	
	for (i=0;i<8;i++) {
		filterDOWNone();
	}
  
	// Make WIDE if saved setting says so
  if (mySettings.filterMode != NARROW) {
    for (i=0;i<8;i++) {
      filterUPone();
    }		    
  }
	//###
	myStateMachine.currentState = 0;

	//Initialise screen in state 0
	ssd1306ClearScreen();	
  serviceBattery();
	displayFreq(mySettings.freq, battery_state);
	ssd1306Refresh();
	
	//Mute: 1 = mute, 0 = audio
  rxMUTE = 0;
	
	//Send call sign welcome CW
	yackinhibit(ON);  //side tone greeting to confirm the unit is alive
	yackstring(callStr);
	yackinhibit(OFF);
		
	/********************************************
	Main program loop
	********************************************/
	// Run in this loop now until death 
	for(;;) {	
		if (txKeyed == 0) {
			i++;
			
			if (myStateMachine.currentState == 0) {
				serviceFreq(&mySettings);
			}
      else if ((myStateMachine.currentState > Vol) && (myStateMachine.currentState != M1R)) {
        // Option to exit the menu with a press of the key
        if ((DITPIN == 0) || (DAHPIN == 0)) {
          yackinhibit(OFF);	
          myStateMachine.currentState = 0;
          ssd1306ClearScreen();	
          displayFreq(mySettings.freq, battery_state);
          ssd1306Refresh();              
          yackdelay(5);
        }
      }
			
			if (enableMemoryReplay == 1) {
				countDownMemoryTimer--;
				if (countDownMemoryTimer == 0) {
					//myStateMachine.currentState == M1p;
					myStateMachine.currentState = 5;
					enableMemoryReplay = 0;
					memoryReplayNow = 1;			
				}
			}
			
			uint8_t write_eeprom = serviceMenu(&myStateMachine, &mySettings);
            
      if (write_eeprom == 1) {
        // Ack that EEPROM is being saved, but don't TX it
        yackinhibit(ON);  
        yackstring("T");
        yackinhibit(OFF);
                
        eeprom_update_byte(&magic, MAGPAT);
        strncpy(ram_vars.e_call, callStr, MAX_CALLSIGN_LEN);
        ram_vars.e_kmod = mySettings.keyMode;
        ram_vars.e_kwpm = wpm;
        ram_vars.e_filt = mySettings.filterMode;
        ram_vars.e_band = mySettings.band;
        ram_vars.e_replay_time = mySettings.autoReplay;
        ram_vars.e_increment = mySettings.increment;
        eeprom_update_block(&ram_vars, &ee_vars, sizeof(eesave_t));
      } 
            
			// 1 second tick
			if (i == 200) {									
				serviceBattery();
				i = 0;
			}
		}
		
		if (battery_state == 4) {
		  // Battery is low, so disable tx
	    yackinhibit(ON);  
	    yackstring(" BAT LOW ");
    }
	  else {
		  // Service keyer/transmitter code
      yackbeat();
      if (straight_key == 0) {
        yackiambic(OFF);
      }
      else {
        service_straight_key();
      }
    }
  }	
}

static void service_straight_key(void) {
  switch (sk_state)	{	
    // idle
    // TX not keyed, check if DITPIN == 0
    case 0:	
      {
        if (DITPIN == 0) {
          // Keyed after idle state
          //txKeyed = 1;
          sk_timer = 50;
          txKeyed = 1;
          
          transition_to_tx();
          
          //rxMUTE = 1;
          //cli();
          //si5351_clock_enable(SI5351_CLK2, 1);					
          //sei();  
                    
          key(DOWN);
          enableMemoryReplay = 0;                
          sk_state += 1;  
          break;
        }
        else {
          break;
        } 
      }

      // Gap between elements?
    case 1:
      {
        if (DITPIN == 0) {
          key(DOWN);
          sk_timer = 50;
          break;
        }
        else if (sk_timer > 0) {
          key(UP);                
          sk_timer--; // Count down   
          break;
        }
        // timer must be zero
        else {
          key(UP);
          sk_state = 2;
        }
      }     
    // End of tx 
    case 2:
      {
        key(UP);
        transistion_to_rx();
        //txKeyed = 0;
        //rxMUTE = 0;
        //yackbeat();
        //cli();
        //si5351_clock_enable(SI5351_CLK2, 0);					
        //sei(); 
        sk_state = 0;
      }    
  }
}       
 
/*************************************************************************
//Initialise
*************************************************************************/
static void initMicro(void) {
	DDRA = ddrPORTA; 
	DDRB = ddrPORTB;
	DDRC = ddrPORTC;
	DDRD = ddrPORTD;	
	// Set all Port D pins as HIGH
	PORTA = 0xF8;			//VSWR ADC low
	PORTB = 0xFF;
	PORTC = 0xFF;
	// TXKEY always off
	PORTD = 0xFB;

	//RFSWMINS = 0;
	//RFSWPLUS = 0;

	//Enable hardware interupt
	EICRA |= _BV(ISC21); //Trigger on falling edge of INT0
	PCICR |= _BV(PCIE2); // Pin Change Interrupt Enable 2, PCINT23..16 pin will cause an interrupt
	PCMSK2 |= _BV(PCINT23); 
	//EIMSK |= _BV(INT2);  //Enable INT0	
	
	/*
	CS02 CS01 CS00
	Description
	0 0 0 No clock source (Timer/Counter stopped)
	0 0 1 clk I/O /(No prescaling)
	0 1 0 clk I/O /8 (From prescaler)
	0 1 1 clk I/O /64 (From prescaler)
	1 0 0 clk I/O /256 (From prescaler)
	1 0 1 clk I/O /1024 (From prescaler)
	1 1 0 External clock source on T0 pin. Clock on falling edge.
	1 1 1 External clock source on T0 pin. Clock on rising edge.
	*/
	
	
	//ASSR=(0<EXCLK) | (0<AS2);
	// enable timer overflow interrupt for both Timer0 and Timer1
	// Timer 0 for sidetone
  TIMSK0=(1<<OCIE0A);
  TCCR0A = _BV(WGM01);  // Mode = CTC    
  //TIMSK0=(1<<TOIE0);
	// set timer0 counter initial value to 0
  TCNT0=0x00;
  // start timer0 with /64 prescaler
  TCCR0B = (1 << WGM01) | (0<<CS02) | (1<<CS01) | (1<<CS00);
  // 96 =  651 Hz
  // 100 = 625 Hz    	
  OCR0A = 96;
    
	//Timer1 for yack beat, prescale 64, count to 1250 then overflow 
	//using compare timer counter reg
	TIMSK1=(0<<TOIE1);
  TCNT1=0x00;
  // lets turn on 16 bit timer1 also with /64
  TCCR1B |=   (1 << WGM12) | (0 << CS12) | (1 << CS11) | (1 << CS10);
  //OCF1A = 1;
  OCR1A = 625;
}

/*************************************************************************
//Interrupts
*************************************************************************/
ISR(TIMER0_COMPA_vect ) {
	STPIN = ~STPIN;
}

ISR(PCINT2_vect ) {
	storedRotA = ROTA;
	storedRotB = ROTB;
	rotEncChange = 1;
	enableMemoryReplay = 0;
}	

/*************************************************************************
//Subroutines
*************************************************************************/

static void serviceFreq(struct systemSettings *setting) {
	uint32_t newFreq = 0;
	if (rotEncChange == 1) {
    if (storedRotA == storedRotB) {
      if ((setting->freq - setting->increment )> setting->lowerFreq) {			
        setting->freq -= setting->increment;
        setting->ritFreq -= setting->increment;
      }			
    }
    else if (storedRotA != storedRotB) {
      if ((setting->freq + setting->increment) < setting->upperFreq) {
        setting->freq += setting->increment;
        setting->ritFreq += setting->increment;
      }
    }
          
    //now update the new frequency
    newFreq = setting->freq;
      
    //cli();
    si5351aSetFrequency(newFreq);
    si5351aSetTXFrequency((newFreq / 4) - TXOFFSET);	
    //sei();
    displayFreq(newFreq, battery_state);
    ssd1306Refresh();

    rotEncChange = 0;
	}
}

static uint8_t serviceMenu(struct menuStateMachine *state, struct systemSettings *setting) {
	uint8_t click = 0;
	uint8_t inc = 0;
	uint8_t dec = 0;
	uint16_t newStep = 0;
	uint8_t i;
	uint8_t longclick = 0;
	uint8_t save = 0;
    
	if (ROTSEL == 0) {
		if (state->currentState == 0) {
			word timer = YACKSECS(1);

			while(timer && (ROTSEL == 0))  {
				timer--;
				yackbeat();
			}
			while (ROTSEL == 0) {};
			
			if (timer == 0) {
				longclick = 1;
				state->currentState = 3;
			}
			else {
				if (timer < 180) {
					click = 1;
				}				
			}
		}
		else {
			state->pbCounterOn += 1;
			if (state->pbCounterOn == 5) {
				click = 1;
			}
		}
	}
	else {
		state->pbCounterOn = 0;	
	}
		
	if (click == 1) {
		//Gone round the loop, but need to refresh to the current
		//frequency
		if ((state->currentState == 2) || (state->currentState == 11)) {
      yackinhibit(OFF);	
			state->currentState = 0;
			ssd1306ClearScreen();	
			displayFreq(setting->freq, battery_state);
			ssd1306Refresh();
		}
		else if (state->currentState == 1) {
			//In RIT, want to advance through menu, reset F back to non-RIT freq
			cli();
			si5351aSetFrequency(setting->freq);
			sei();
			state->currentState += 1;
		}
		else {
			state->currentState += 1;
		}		
	}	
	
	if (rotEncChange == 1) {
		if (storedRotA != storedRotB){
			inc = 1;
		}
		else if (storedRotA == storedRotB){
			dec = 1;
		}
		
		rotEncChange = 0;
	}
	    
	switch (state->currentState) {        
			case	Frequency: 	// 0
				{
				//
				break;
			}			
			case	RIT: 		// 1
				{
				if (inc == 1) {	
					setting->ritFreq += 40;
					si5351aSetFrequency(setting->ritFreq);
					clearMainArea();
					displayFreqSmall(setting->freq, setting->ritFreq);					
				}
				else if (dec == 1) {
					setting->ritFreq -= 40;
					si5351aSetFrequency(setting->ritFreq);
					clearMainArea();
					displayFreqSmall(setting->freq, setting->ritFreq);					
				}
				else if (click == 1) {
					clearMainArea();
					displayFreqSmall(setting->freq, setting->ritFreq);
				}
				break;
			}
			case  Vol: 		// 2
				{	
				if (inc == 1 && setting->volume != 9) {
					rxMUTE = 1;	
					volumeUPone();
					rxMUTE = 0;	
					setting->volume += 1;
				    clearMainArea();
				    drawIntNumber(setting->volume);	
				}
				else if (dec == 1 && setting->volume != 0) {
					rxMUTE = 1;
					volumeDOWNone();					
					rxMUTE = 0;	
					setting->volume -= 1;
					clearMainArea();
					drawIntNumber(setting->volume);						
					}
				else if (click == 1) {				
					clearMainArea();
					drawIntNumber(setting->volume);	
				}				
				break;
			}			
			case	FSTEP: 		// 3
				{			
				if (inc == 1 || dec == 1) {
					newStep = serviceStep(inc,dec,((setting->increment)/4));
					setting->increment = (newStep*4);		
					clearMainArea();								
					drawIntNumber((setting->increment)/4);
          save = 1;
				}
				else if (longclick == 1) {		
          yackinhibit(ON);		
					clearMainArea();					
					drawIntNumber((setting->increment)/4);
				}
				break;
			}						
			case	Tune: 		// 4
				{
				if ((inc == 1) || (dec == 1)) {
					clearMainArea();
					drawMainArea(0);
 
					RFSWMINS = 0;
					RFSWPLUS = 0;                    
          yackbeat();
          RFSWMINS = 0;
					RFSWPLUS = 1;
          yackbeat();
					RFSWMINS = 0;
					RFSWPLUS = 0;                     
                    
          yacktune();
                    
          RFSWMINS = 1;
					RFSWPLUS = 0;
          yackbeat();
          RFSWMINS = 0;
					RFSWPLUS = 0;  
                    
          yackinhibit(OFF);	
          state->currentState = 0;
          ssd1306ClearScreen();	
          displayFreq(setting->freq, battery_state);
          ssd1306Refresh();    
          yackdelay(5);
				}		
				else if (click == 1) {
					clearMainArea();
					drawMainArea(0);
				}
				
				break;
			}		
			case  M1P: 		// 5			
				{	
				if ((inc == 1) || (dec == 1) || memoryReplayNow == 1) {
					clearMainArea();				
					memoryReplayNow = 0;

					drawMainArea(1);
					//ssd1306Refresh();
					displayChangeStateIcon(state->currentState);					
					ssd1306Refresh();
          if (inc == 1) {
            sprintf(cqStr, "CQ CQ CQ de");
          }
          else if (dec == 1) {
            sprintf(cqStr, "CQ SOTA CQ SOTA de");
          }
                    
					memoryCQ();	
					
					//###Put this into a seperate function
					state->currentState = 0;
					ssd1306ClearScreen();	
					displayFreq(setting->freq, battery_state);
					ssd1306Refresh();
					if (setting->autoReplay != 0) {
						enableMemoryReplay = 1;
						countDownMemoryTimer = 200 * setting->autoReplay;
					}
				}					
				else if (click ==1) {	
					clearMainArea();								
					drawMainArea(0);
				}			
				break;
			}	
			case  M1R: 		// 6
				{
				if ((inc == 1) || (dec == 1)) {
					clearMainArea();
					drawMainArea(2);
					//ssd1306Refresh();
					displayChangeStateIcon(state->currentState);					
					ssd1306Refresh();
	
					yackmessage(RECORD,1); 	
	
					//yackinhibit(ON);
					//yackmessage(PLAY,1);

						
					//###Put this into a seperate function
					state->currentState = 0;
					ssd1306ClearScreen();	
					displayFreq(setting->freq, battery_state);
					ssd1306Refresh();
					return 1;
				}					
				else if (click == 1) {				
					drawMainArea(0);
				}			
				break;
			}
			case  Wpm: 		// 7
				{		
				if (inc == 1 && wpm < MAXWPM) {
					wpm += 1;
					wpmcnt=(1200/YACKBEAT)/wpm; // Calculate speed	
					clearMainArea();
					drawIntNumber(wpm);
                    save = 1;                    
				}
				else if (dec == 1 && wpm > MINWPM) {
					wpm -= 1;
					wpmcnt=(1200/YACKBEAT)/wpm; // Calculate speed
					clearMainArea();
					drawIntNumber(wpm);
                    save = 1;
					}
				else if (click == 1) {	
					clearMainArea();
					drawIntNumber(wpm);								
					break;
				}						
		
				break;
			}	
			case  KMOD: 		// 8
				{
				if (inc == 1 || dec == 1) {
					setting->keyMode = serviceKeyerMode(inc,dec,setting->keyMode);				
					clearMainArea();	
					drawMainAreaSmall(setting->keyMode);
          save = 1;								
				}
				else if (click == 1) {		
					clearMainArea();		
					drawMainAreaSmall(setting->keyMode);
				}

				break;
			}
			case	Fil: 		// 8
				{			
				if (inc == 1 || dec == 1) {
					if (setting->filterMode == WIDE) {
						rxMUTE = 1;	
						for (i=0;i<8;i++) {
							filterDOWNone();
						}	
						rxMUTE = 0;	
						setting->filterMode = NARROW;
					}
					else if (setting->filterMode == NARROW) {
						rxMUTE = 1;	
						for (i=0;i<8;i++) {
							filterUPone();
						}					
						rxMUTE = 0;	
						setting->filterMode = WIDE;
					}	
          save = 1;
					clearMainArea();
					drawMainAreaSmall(setting->filterMode + Narrow);					
				}
				
				else if (click == 1) {				
					clearMainArea();
					drawMainAreaSmall(setting->filterMode + Narrow);	
				}	

				break;
			}
			case	MAR: 		// 10
				{	
				if (inc == 1 && (setting->autoReplay < 10)) {
					setting->autoReplay += 1;
				  clearMainArea();
					drawIntNumber(setting->autoReplay);	
          save = 1;			
				}
				else if (dec == 1 && (setting->autoReplay != 0)) {
					setting->autoReplay -= 1;
				  clearMainArea();
					drawIntNumber(setting->autoReplay);					
          save = 1;
				}
				else if (click == 1) {	
				  clearMainArea();
					drawIntNumber(setting->autoReplay);
				}	
				break;
			}
			case	Band: 		// 11
				{	
				if (inc == 1 || dec == 1) {
					if (setting->band == BAND1) {
						setting->band = BAND2;
						ChangeBand(setting->band, &*setting);
					}
					else if (setting->band == BAND2) {
						setting->band = BAND1;
						ChangeBand(BAND1, &*setting);												
					}	
          save = 1;
					clearMainArea();	
					drawIntNumber(setting->band);
				}
					

				else if (click == 1) {		
					clearMainArea();	
					drawIntNumber(setting->band);	
				}	
				break;   
			} 
		}		
	if ((inc == 1 || dec == 1) || (click == 1) || (longclick == 1)) {
		displayChangeStateIcon(state->currentState);
		ssd1306Refresh();		
	}
  
  return save;
}

uint16_t getVSWR(void) {
	//Vrev PA0 ADC0 
	//Vfwd PA1 ADC1
	uint16_t measVfwd;
	uint16_t measVrev;
	
	//****Vfwd
	//ADMUX |= (0<<MUX2) | (0<<MUX1) | (1<<MUX0); // switch ADC to 0000 ADC1
	ADMUX = 0b00000000;
	//ADCSRA |= (1 << ADATE);  // Set ADC to Free-Running Mode 
	ADCSRA |= (1 << ADEN);  // Enable ADC 
	ADCSRA |= (1 << ADSC);  // Start A2D Conversions 
	while (ADCSRA & (1<<ADSC));
	
	
	ADCSRA |= (1 << ADEN);  // Enable ADC 
	ADCSRA |= (1 << ADSC);  // Start A2D Conversions 
	while (ADCSRA & (1<<ADSC));
	
	uint8_t theLowADC = ADCL;
	uint16_t theTenBitResults = ADCH<<8 | theLowADC;
	
	float meas_pwr;
	meas_pwr = ((5 * (float)theTenBitResults)/1023);
	meas_pwr = meas_pwr * 1000;
	measVfwd = (uint16_t)meas_pwr;

	//********************
	// V reflected
	//********************
	ADMUX = 0b00000001;
	ADCSRA |= (1 << ADEN);  // Enable ADC 
	ADCSRA |= (1 << ADSC);  // Start A2D Conversions 
	while (ADCSRA & (1<<ADSC));
	
	ADCSRA |= (1 << ADEN);  // Enable ADC 
	ADCSRA |= (1 << ADSC);  // Start A2D Conversions 
	while (ADCSRA & (1<<ADSC));
		
	theLowADC = ADCL;
	theTenBitResults = ADCH<<8 | theLowADC;

	meas_pwr = ((5 * (float)theTenBitResults)/1023);
	meas_pwr = meas_pwr * 1000;
	measVrev = (uint16_t)meas_pwr;
	
	// (Vf + Vr) / (Vf - Vr)
	float measSWR = ((float)measVfwd + (float)measVrev) / ((float)measVfwd - (float)measVrev);
	measSWR = measSWR * 10;
	measSWR = measSWR + 0.5;
	
	uint16_t displaySWR = (uint16_t)measSWR;

	return displaySWR;
}
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

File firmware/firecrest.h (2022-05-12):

/* 
 * Copyright 2021 m5evt
 * 
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
 */
 
#ifndef FIRECREST_H
#define FIRECREST_H

#include <avr/eeprom.h>
#include "helper.h"
#include "yack.h"
/*
#define vFWD		SBIT(PINA, 0) 
#define vREV 		SBIT(PINA, 1) 
#define vBAT 		SBIT(PINA, 2) 
#define txVTC		SBIT(PORTA, 3) 
#define txON		SBIT(PORTA, 4) 
#define dit 		SBIT(PORTA, 5) 
#define dah 		SBIT(PORTA, 6) 
#define rotSEL		SBIT(PINA, 7)

#define RFSWMINS	SBIT(PORTB, 0) 
#define RFSWPLUS	SBIT(PORTB, 1) 
#define indtxLED2	SBIT(PORTB, 2) 
#define heartLED1	SBIT(PORTB, 3) 
#define dispPWR		SBIT(PORTB, 4) 
//#define mosi		SBIT(PORTB, 5) 
//#define miso		SBIT(PORTB, 6) 
//#define sck		SBIT(PORTB, 7) 

//#define 			SBIT(PORTC, 0) 		// i2c
//#define 			SBIT(PORTC, 1)	// i2c 

#define VOLCS		SBIT(PORTC, 3) 
#define FILCS		SBIT(PORTC, 4) 
#define VOLUD		SBIT(PORTC, 5) 
#define rotB		SBIT(PINC, 6) 
#define rotA		SBIT(PINC, 7) 

//#define rx0		SBIT(PORTD, 0)
//#define tx0		SBIT(PORTD, 1)
#define uartPWR		SBIT(PORTD, 2)
//#define uartPWR	SBIT(PORTD, 3)	//Reserved
#define dispDC		SBIT(PORTD, 4)
#define dispRST		SBIT(PORTD, 5)
#define dispCS		SBIT(PORTD, 6)
//#define sidetone	SBIT(PORTD, 7)	// Reserved

*/

//********Yack
#define	KEYINP	PINA
#define KEYTX		SBIT(PORTD, 2) 
#define DITPIN	SBIT(PINA, 5) 								
#define DAHPIN	SBIT(PINA, 6) 
#define BTNPIN	SBIT(PINA, 7) 

//********Tx
#define rxMUTE SBIT(PORTD, 6)

//********General system settings
#define ROTA		SBIT(PINC, 7) 	//Rotary encoder B
#define ROTB		SBIT(PINC, 6) 	//Rotary encoder A
#define ROTSEL	SBIT(PINC, 2)	//Main push button

#define RFSWMINS	SBIT(PORTB, 0) 
#define RFSWPLUS	SBIT(PORTB, 1) 

#define VOLCS		SBIT(PORTC, 3) 
#define FILCS		SBIT(PORTC, 4) 
#define VOLUD		SBIT(PORTC, 5) 

#define BANDA		SBIT(PORTD, 3) 	
#define BANDB		SBIT(PORTD, 4) 	

#define STPIN		SBIT(PORTD, 5)

#define ddrPORTA	0b10011000
#define ddrPORTB	0b11111111
#define ddrPORTC	0b00111011
#define ddrPORTD	0b11111111

//OLED Defs
#define SSD1306_CS_PORT 	PORTB
#define SSD1306_CS_PIN		4
#define SSD1306_DC_PORT 	PORTB
#define SSD1306_DC_PIN		2
#define SSD1306_RST_PORT	PORTB
#define SSD1306_RST_PIN		3

#define SSD1306_SCLK_PORT 	PORTB
#define SSD1306_SCLK_PIN  	7
#define SSD1306_SDAT_PORT 	PORTB
#define SSD1306_SDAT_PIN  	5

#define NARROW	0
#define WIDE		1

#define BAND1		10
#define BAND2		14

#define BAND1_UPPER 	10150000
#define BAND1_LOWER		10100000
#define BAND1_F			  10118000

#define BAND2_UPPER	  14100000	
#define BAND2_LOWER   14000000	
#define BAND2_F			  14062000

// If changing this, must change timer in init micro
#define TXOFFSET  650

#define MAX_CALLSIGN_LEN 15

char callStr[15];

/*    
extern volatile unsigned int txKeyed = 0;    
extern uint8_t enableMemoryReplay = 0;		
extern uint8_t battery_state = 0;
extern volatile unsigned int txKeyed;
*/


#define		MAGPAT			0xA5    // If this number is found in EEPROM, content assumed valid

typedef struct {
	char e_call[MAX_CALLSIGN_LEN];
  uint8_t e_kmod;
  uint8_t e_kwpm;
  uint8_t e_filt;
  uint8_t e_band;
  uint8_t e_replay_time;
  uint16_t e_increment;
} eesave_t;

struct systemSettings {
	uint16_t increment;
	uint32_t freq;
	uint32_t ritFreq;
	uint32_t upperFreq;
	uint32_t lowerFreq;
	uint16_t volume;
	uint8_t filterMode;
	uint8_t autoReplay;
	uint8_t band;
	uint8_t keyMode;
};

struct menuStateMachine {
	uint8_t currentState;
	uint8_t txState;
	uint8_t pbCounterOn;
	uint8_t pbCounterOff;
};

enum menuStateDescript {
	Frequency,
	RIT,
	Vol,
	FSTEP,
	Tune,
	M1P,
	M1R,
	Wpm,
	KMOD,
	Fil,
	MAR,
	Band
};       

enum menuDetailsDescript {
    OffTest,
    On,
    Rec,
    Narrow,
    Wide,
    IA,
    IB,
    Str,
    Ul
};  

/*************************************************************************
//Function Prototypes
*************************************************************************/
extern uint16_t getVSWR(void);
extern void transistion_to_rx(void);
extern void transition_to_tx(void);
extern void service_vswr(void);
extern void disable_memory_replay(void);
#endif

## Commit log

2021-01-03 kicad and firmware
    [Firecrest.kicad_pcb, Firecrest.sch, synthPCB_v2.kicad_pcb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]
2022-05-12 Bug fixes and code tidy up
    [firecrest.h, main.c]

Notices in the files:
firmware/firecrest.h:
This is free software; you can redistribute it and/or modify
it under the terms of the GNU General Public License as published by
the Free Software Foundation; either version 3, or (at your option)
